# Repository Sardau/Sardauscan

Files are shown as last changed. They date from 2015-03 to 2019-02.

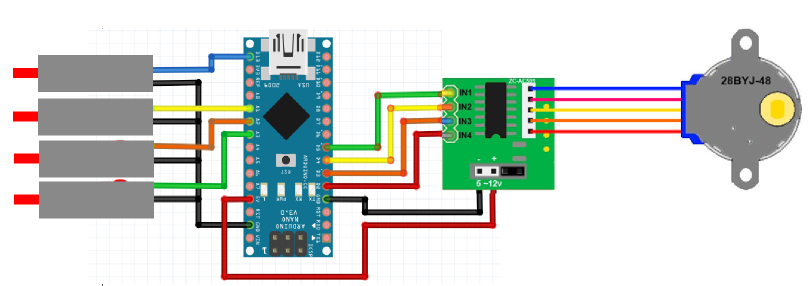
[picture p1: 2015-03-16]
FirmWare/Wiring.png

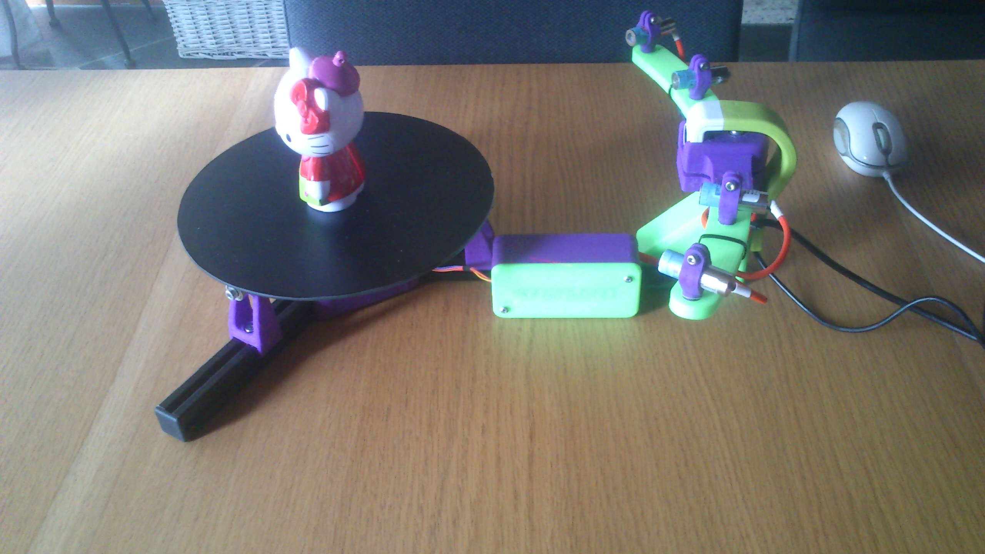
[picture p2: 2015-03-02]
STL/DSC_0299.jpg

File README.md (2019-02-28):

# Sardauscan

Sardauscan is a 3D laser scanner aimed to cost less than 30$

It is quite possibly the lowest-cost 3D scanner currently available.

Hardware List: 
- Arduino Nano
- 1 to 4 line lase
-a a micro geared stepper (28BYJ-48)
- Hercule HD Twist webcam

This software is written in C# and Winforms, and is based on a system of tasks and processes.

A task is an operation, such as: scan, save file, filter noise, smooth, or build mesh.

A process is simply a list of tasks.

It is possible to develop and add your own tasks via plugins.

The software will not be linked to any specific hardware.
Using plugins, one could add harware controllers for additional cameras, turn tables and lasers.
For example, if you wish to use another scanner or webcam.

Directory "Firmware" => code for the arduino
Directory "STL" the source stl and 123Design file.
Directory "Sardauscan" => the client software

The code is written in C# and Winforms and is build on Visual Basic 2010, for Windows.

the firmware needed for the Adafruit Motor Shield library can be found here:
https://github.com/adafruit/AccelStepper

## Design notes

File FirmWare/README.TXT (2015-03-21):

Hello you must install the accellstepper library in arduino environement before compile/upload it it

https://github.com/adafruit/AccelStepper

tips (from Mark Benson)
If anyone else is having problems with a BYJ48 stepper not doing anything, change the HALFSTEP value to 4 & REVOLUTION_STEP to 2048 in configuration.h.

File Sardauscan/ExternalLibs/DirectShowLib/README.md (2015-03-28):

Library **DirectShowLib** is not a part of Camera_Net library.

DirectShowLib is included in repo just to give an ability to build project/solution without any additional work.

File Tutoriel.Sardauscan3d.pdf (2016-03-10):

# Tutoriel d’utilisation du Sardauscan

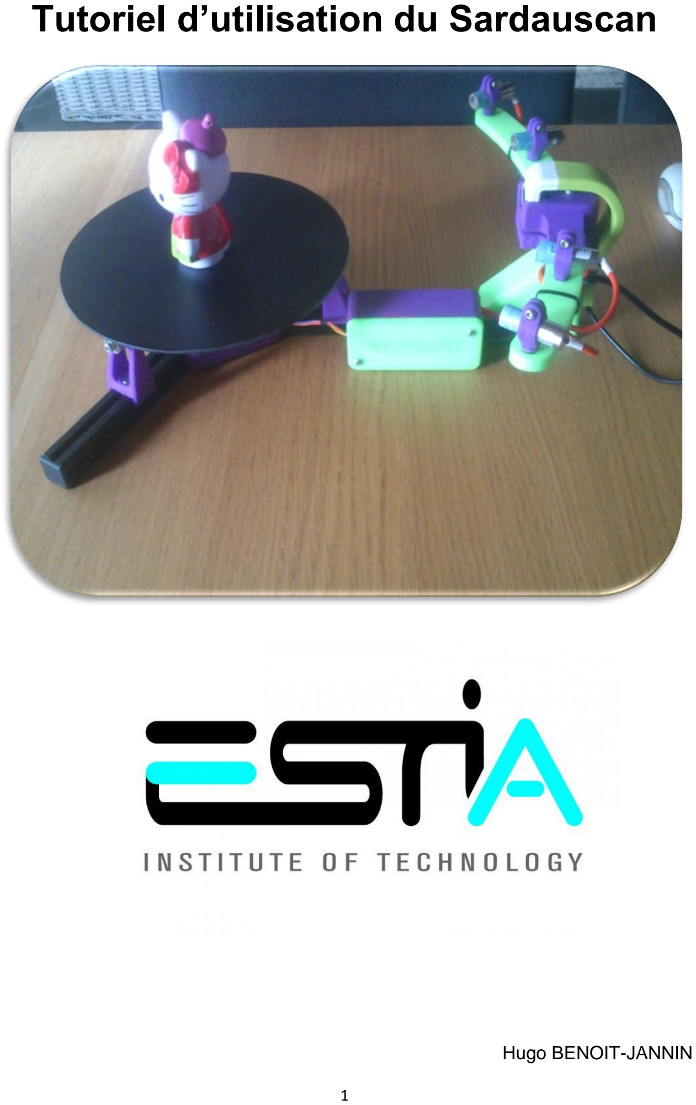
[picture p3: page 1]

Hugo BENOIT-JANNIN

Ce manuel d’utilisation traite uniquement des démarches pour calibrer et scanner un objet en 3D avec le scanner Sardauscan, la partie conception du scanner ne sera pas abordée dans ce tutoriel. Si vous souhaitez construire votre Sardauscan rendez-vous sur le site suivant : http://www.thingiverse.com/thing:702470 où tout est indiqué (matériel à acheter, programme pour l’Arduino, design des pièces à imprimés).

Le Sardauscan est un scanner 3D à bas coût et open-source, pouvant rivaliser avec de très bon scanner « plug and play » coûtant d’avantage et fermés à toute modification.

Le Sardauscan utilise des faisceaux lumineux de couleur rouge, qui seront détectés par la Webcam, la webcam enregistre la déformation du faisceau lumineux pour ensuite la traduire comme image sur le logiciel.

Prévoir un grand espace autour du scanner pour éviter que le scan enregistre les formes trop proches, ce qui provoque du bruit et fausse le scan.

# Sommaire

- Installation du logiciel d’interface __________________________3-8
- Calibration du matériel________________________________9-17
- Calibration caméra___________________________________10
- Calibration laser_____________________________________11
- Calibration position___________________________________12
- Calibration image laser________________________________13
- Calibration matrice __________________________________14-16
- Scan et traitement _____________________________________17-18
- Quelques scans _______________________________________19-23

## Installation du logiciel d’interface

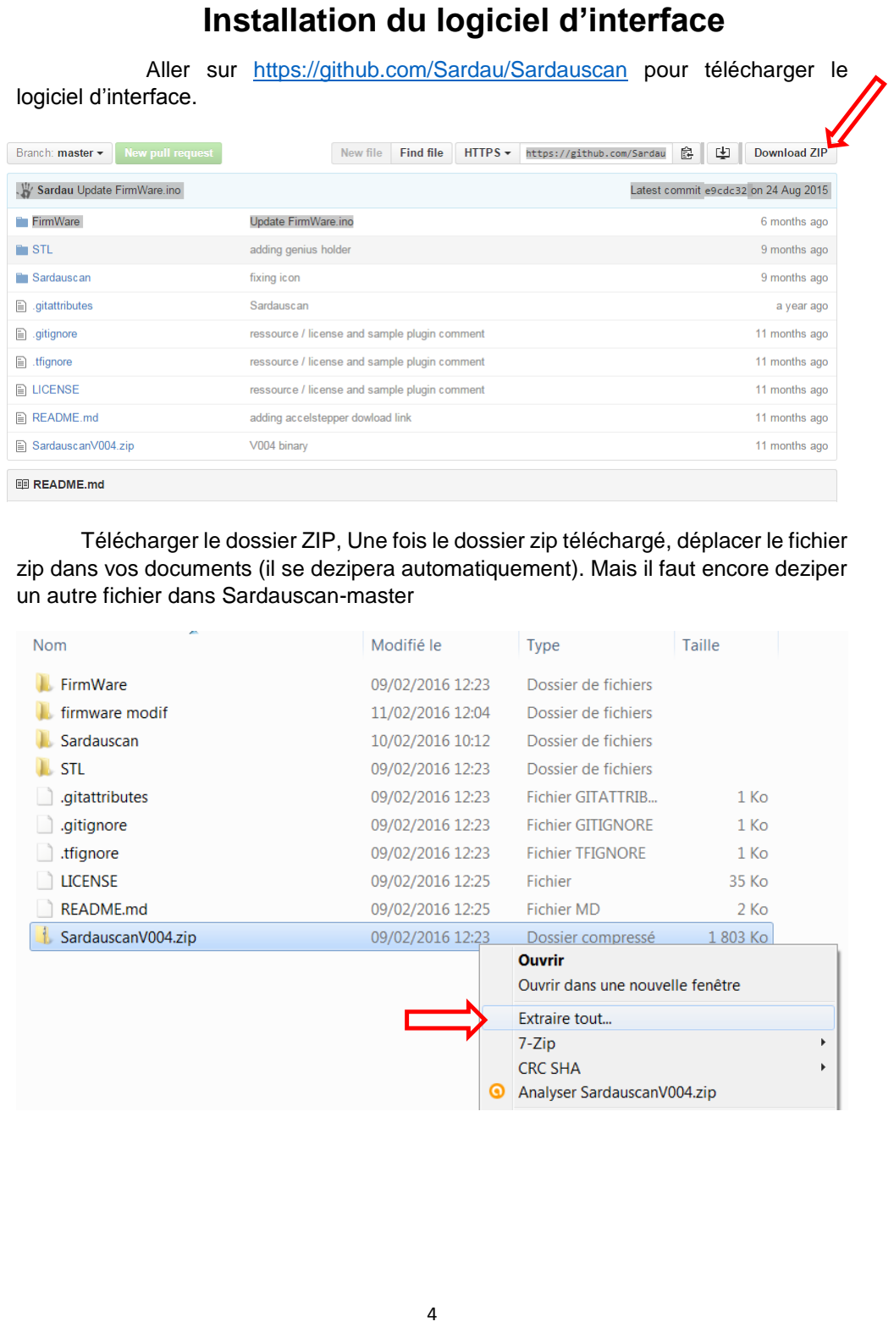
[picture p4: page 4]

Aller sur https://github.com/Sardau/Sardauscan pour télécharger le logiciel d’interface.

Télécharger le dossier ZIP, Une fois le dossier zip téléchargé, déplacer le fichier zip dans vos documents (il se dezipera automatiquement). Mais il faut encore deziper un autre fichier dans Sardauscan-master

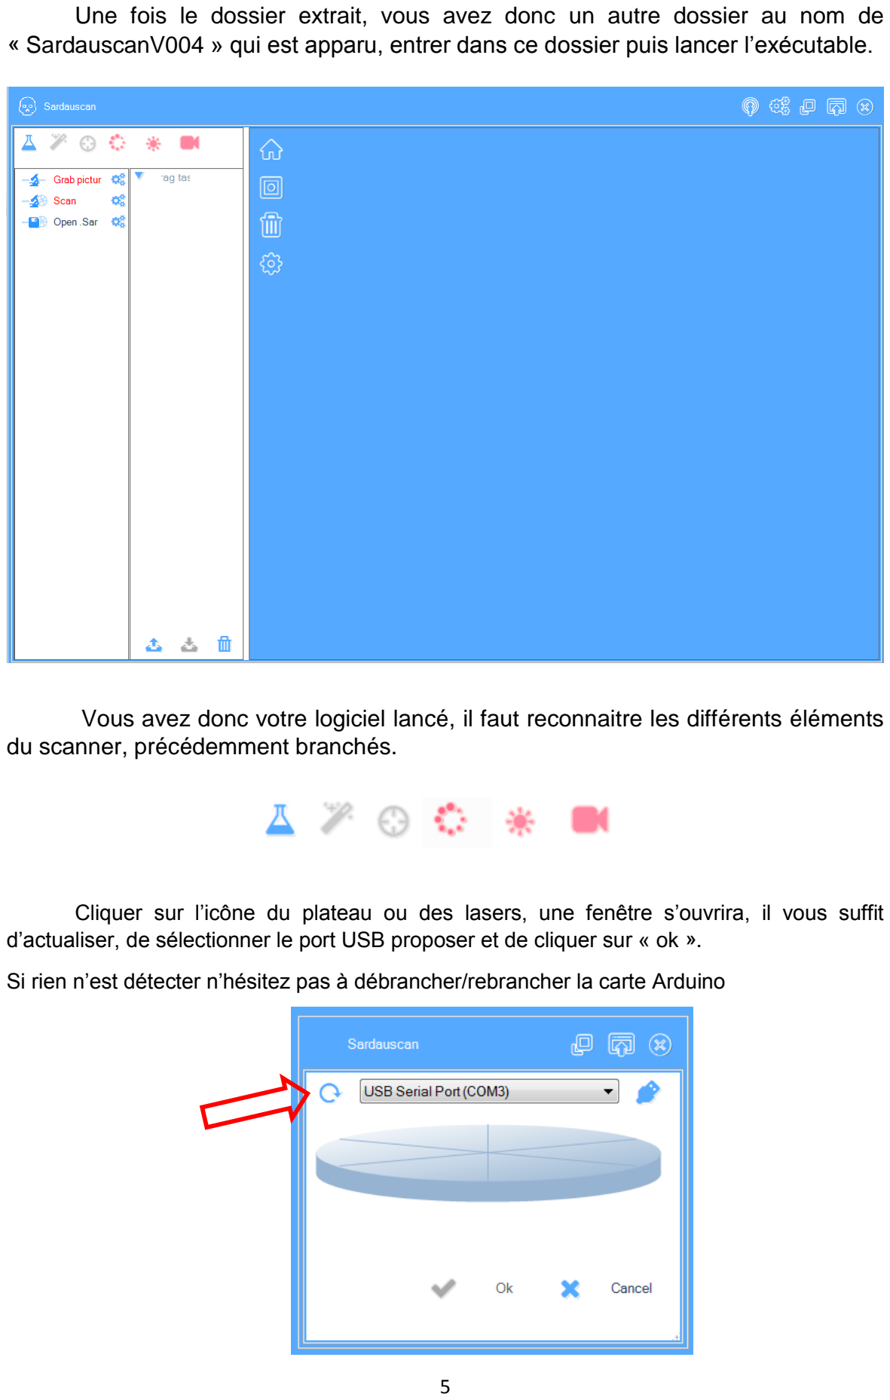
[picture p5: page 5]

Une fois le dossier extrait, vous avez donc un autre dossier au nom de « SardauscanV004 » qui est apparu, entrer dans ce dossier puis lancer l’exécutable.

Vous avez donc votre logiciel lancé, il faut reconnaitre les différents éléments du scanner, précédemment branchés.

Cliquer sur l’icône du plateau ou des lasers, une fenêtre s’ouvrira, il vous suffit d’actualiser, de sélectionner le port USB proposer et de cliquer sur « ok ».

Si rien n’est détecter n’hésitez pas à débrancher/rebrancher la carte Arduino

Pour la caméra vérifier même si l’icône est bleu en effet le logiciel peut avoir reconnu la camera intégrée si vous utilisez un ordinateur portable. Pour retirer la caméra intégrée faire clic droit sur l’icône puis « remove ».

Choisissez alors « Hercules HD Twist » puis cliquer sur « ok »

Vous pouvez normalement utiliser indépendamment chaque laser et le plateau en cliquant sur l’icône laser, puis en activant chaque laser indépendamment.

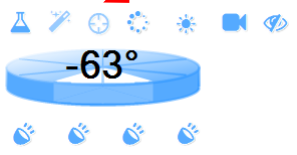
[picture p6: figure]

Il est probable que le plateau ne tourne pas, vérifier si des LEDs sur la carte électronique du moteur sont allumées, si elles sont allumées le plateau fonctionne, si ce n’est pas le cas, il faut modifier quelques paramètres dans le code Arduino.

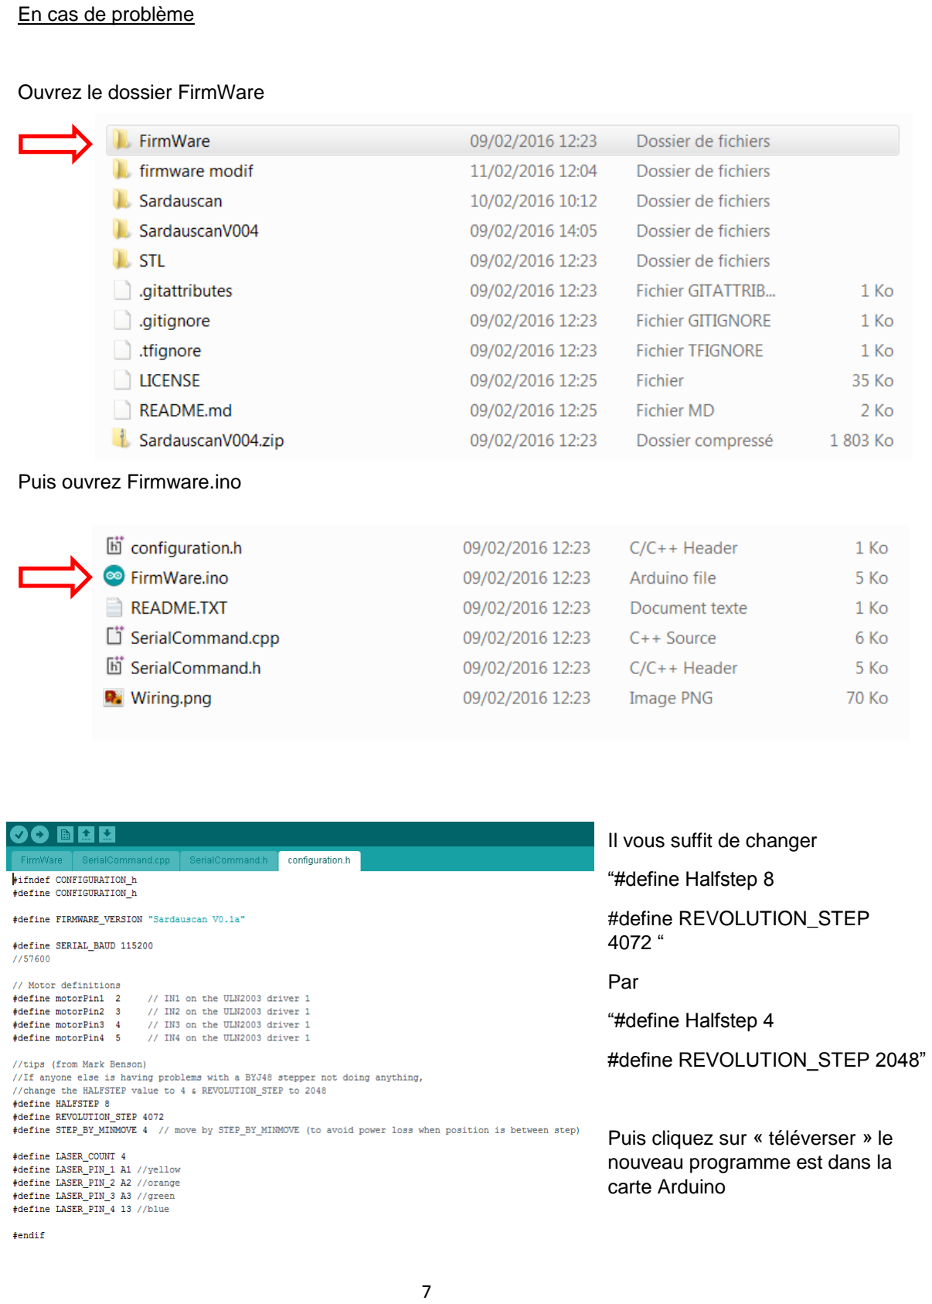
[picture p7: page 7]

En cas de problème

Ouvrez le dossier FirmWare

Puis ouvrez Firmware.ino

Il vous suffit de changer

“#define Halfstep 8

#define REVOLUTION_STEP

4072 “

Par

“#define Halfstep 4

#define REVOLUTION_STEP 2048”

Puis cliquez sur « téléverser » le nouveau programme est dans la carte Arduino

Un message d’erreur peut apparaitre, en effet il peut manquer une librairie dans votre
logiciel Arduino. Pour cela aller sur | https://github.com/adafruit/AccelStepper | et
télécharger le dossier, et renommer le « AccelStepper » en respectant les minuscules/majuscules.

Retourner dans le logiciel Arduino

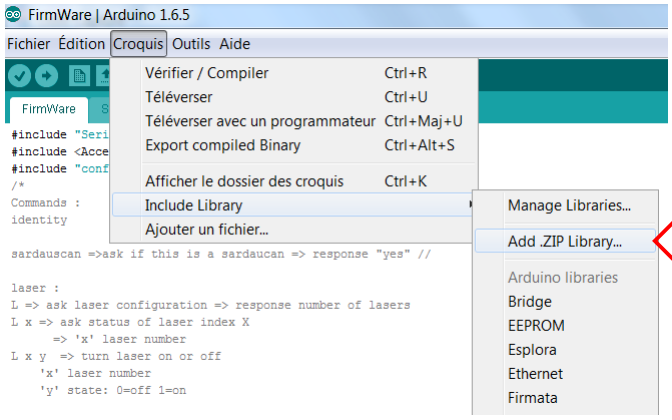
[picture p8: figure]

Ajouter la librairie AccelStepper, puis téléverser le nouveau programme, ce dernier devrait alors s’implanter dans votre Arduino sans soucis.

Votre interface est maintenant prête à l’utilisation, mais il faut maintenant calibrer le scanner.

## Calibration du matériel

Nous allons maintenant calibrer le scanner, cette tâche est la plus longue et la plus compliquée, mais il est nécessaire que le calibrage soit fait avec soin pour obtenir un résultat de bonne qualité, soyez donc patient et précis.

Pour calibrer je vous conseille d’imprimer en 3D un demi-cône (coupé dans la hauteur) et de faire une rainure dans sa hauteur (dans le sens des lasers), faites le de couleur noir, ce qui évite la diffusion de la lumière à travers la matière, ce qui peut fausser notre précision.

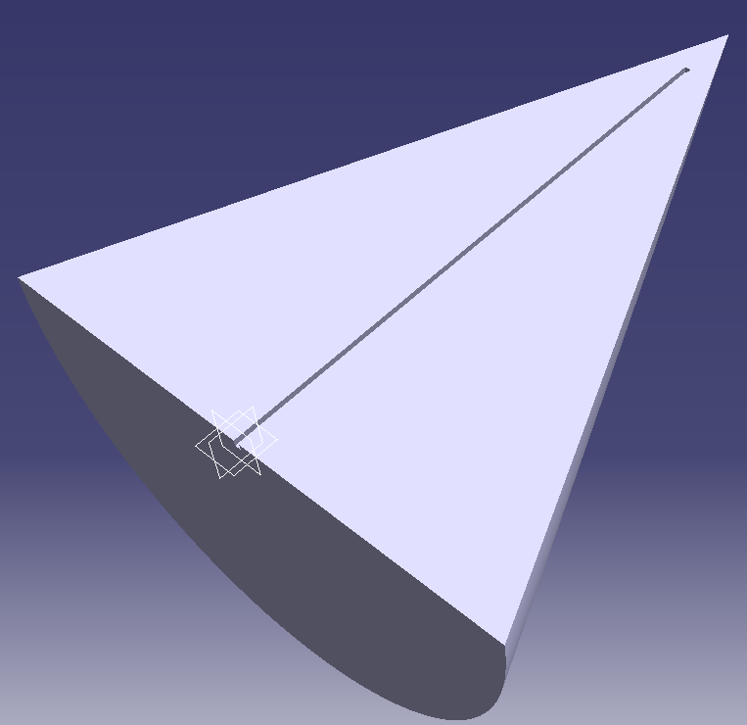
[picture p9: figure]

Vous avez préalablement trouvé le centre de votre plateau tournant si ce n’est pas le cas il faut essayer de le déterminer, vous pouvez vous aidez à l’aide de votre demi-cône et de vos lasers. Posez votre demi-cône sur le plateau et faites passer un laser par son sommet, puis faites tourner le plateau, si le laser reste toujours en son sommet, vous avez trouvé le centre du plateau (marquez son centre pour les prochaines utilisations du scanner).

## Calibration camera

Pour calibrer la camera rien de plus simple, aller dans l’onglet caméra, puis dans la section « Physical calibration »

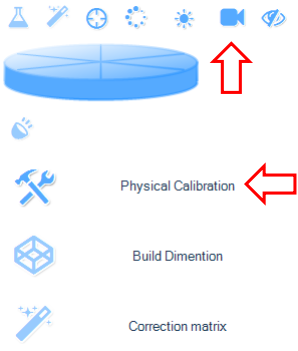
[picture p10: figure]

Il vous suffit de cliquer la barre verte horizontale et de la placer au centre de votre plateau, ainsi votre camera sera calibrée pour les scans ultérieurs.

## Calibration lasers

La calibration des lasers est une des tâches les plus compliquées à effectuer par sa précision. Vous devrez effectuer l’opération pour chaque laser indépendamment. Vous avez besoin de votre demi-cône que vous placerez au centre du plateau, la face plate du côté de la caméra.

Réglez le faisceau lumineux afin d’avoir le plus fin possible en tournant la molette directement sur le laser. Puis diriger le faisceau lumineux dans la rainure du demi-cône (la rainure est au centre du plateau). Sur votre image que vous avez à l’écran vous ne devez pas distinguer le laser derrière la barre verte (voir ci-dessous).

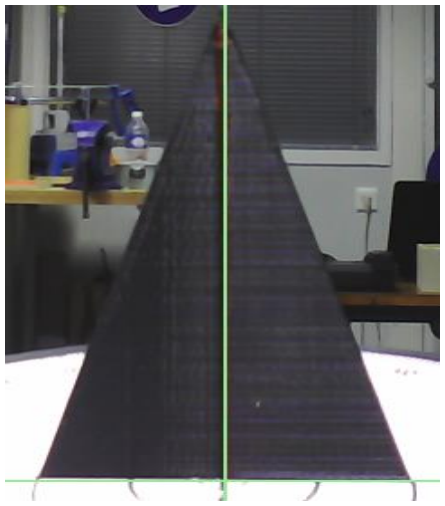
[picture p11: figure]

## Calibration Position

Si ce n’est pas déjà fait, il faut calibrer les dimensions de votre scanner, c’est-à-dire des positions de votre caméra et de vos différents lasers, pour cela allez dans l’onglet « calibrate », puis dans « build calibrate » et rentrez les coordonnées de la caméra.

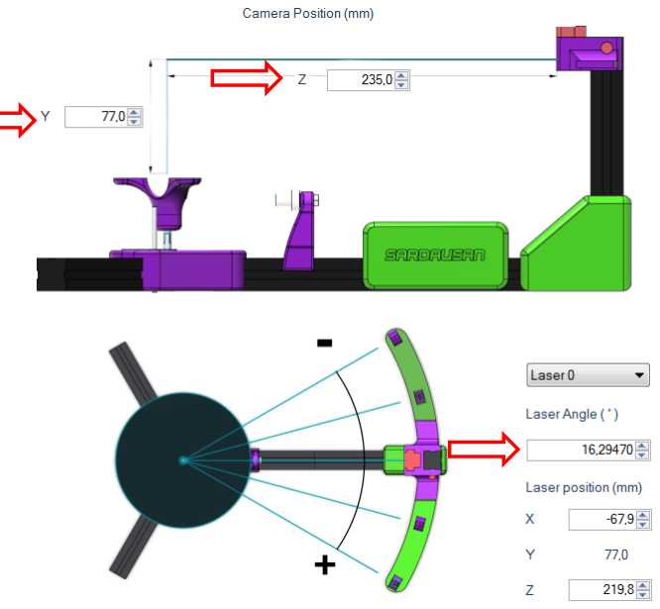
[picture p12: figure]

Conseil : Ne mettez que l’angle du laser en respectant le signe, ses coordonnées s’ajusteront toutes seules. Vérifiez bien tous les angles de laser qui peuvent bouger en réglant les autres lasers.

Conseil : imprimer un rapporteur circulaire que vous collerez sur le plateau

## Calibration de l’image laser

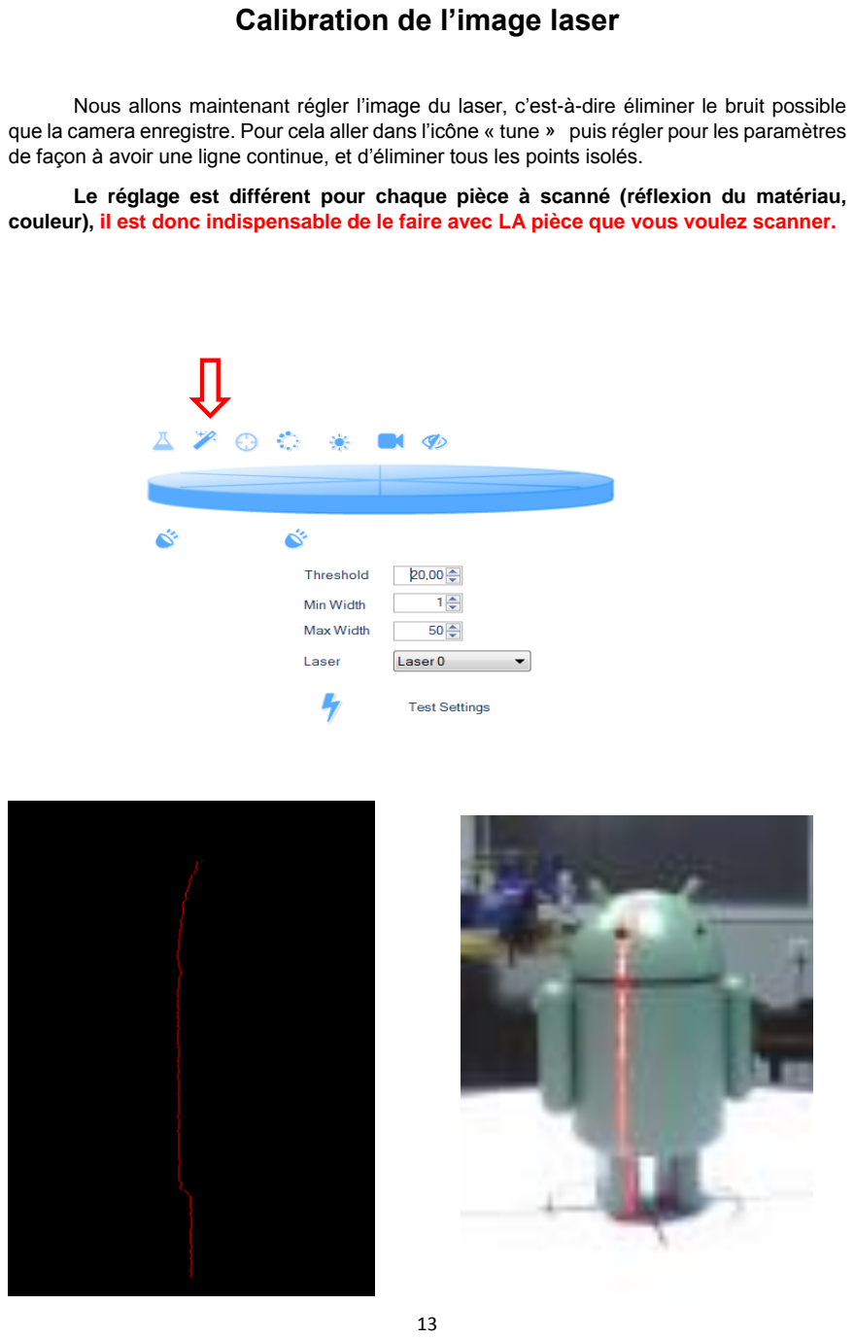
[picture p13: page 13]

Nous allons maintenant régler l’image du laser, c’est-à-dire éliminer le bruit possible que la camera enregistre. Pour cela aller dans l’icône « tune » puis régler pour les paramètres de façon à avoir une ligne continue, et d’éliminer tous les points isolés.

Le réglage est différent pour chaque pièce à scanné (réflexion du matériau, couleur), il est donc indispensable de le faire avec LA pièce que vous voulez scanner.

## Correction de matrice

La correction de matrice est la dernière étape de calibration du scanner et la plus importante. Pour cela prenez une pièce ayant une forme particulière, un tube avec une barre le traversant dans son rayon voir photo suivante

Votre objet de calibration doit avoir une forme simple tout en étant irrégulier (ex : pas de tube simple).

Maintenant aller dans l’onglet « calibrate » puis dans « correction matrix »

Chaque réglage est propre à votre environnement, à vous de le trouver pour obtenir une ligne continue sans point isolé.

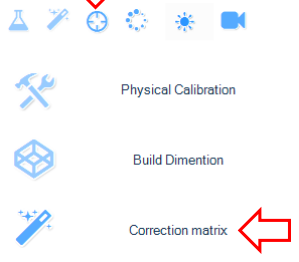
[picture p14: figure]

Poser votre objet de calibrage au centre du plateau, puis lancer un scan rapide. Vous obtiendrez alors des formes dans votre fenêtre (vue de dessus) il vous suffit donc d’aligner vos scans de différentes couleurs pour en faire un seul.

Conseil : Aller voir dans l’onglet « Process » et regarder quelle couleur de scan respecte l’échelle de l’objet scanné, ne pas toucher au scan respectant l’échelle et aligner les autres. Si les scans ne sont pas à l’échelle mais qu’ils sont alignés, une fonction du traitement permet de corriger cette erreur.

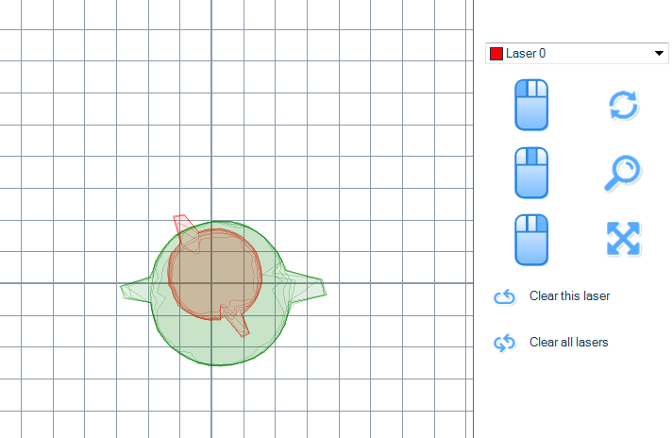
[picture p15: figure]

Ici le vert respecte les dimensions, il faut donc aligner le scanner rouge sur le vert, avant toute manipulation cliquer sur « clear this scan » et faites-le pour chaque scan.

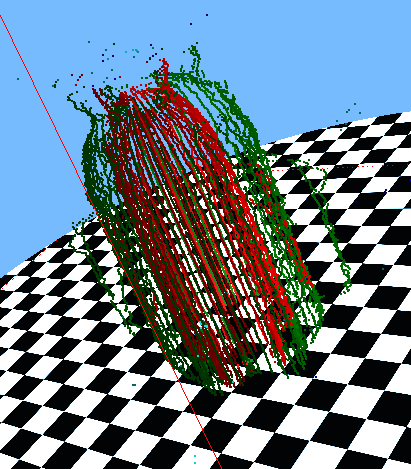
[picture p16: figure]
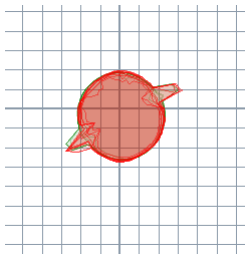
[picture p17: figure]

On remarque dans « process » que le scan rouge est plus « maigre » que le scan vert, et que le scan vert est à bonne échelle, il faut donc s’aligner sur le scan vert.

Votre scan est désormais calibré, nous allons pouvoir procéder aux scans puis au traitement pour éliminer le bruit et lisser les scans.

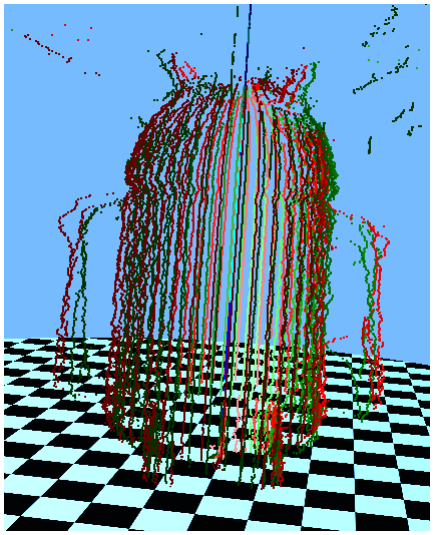
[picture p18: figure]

## Scan et traitement

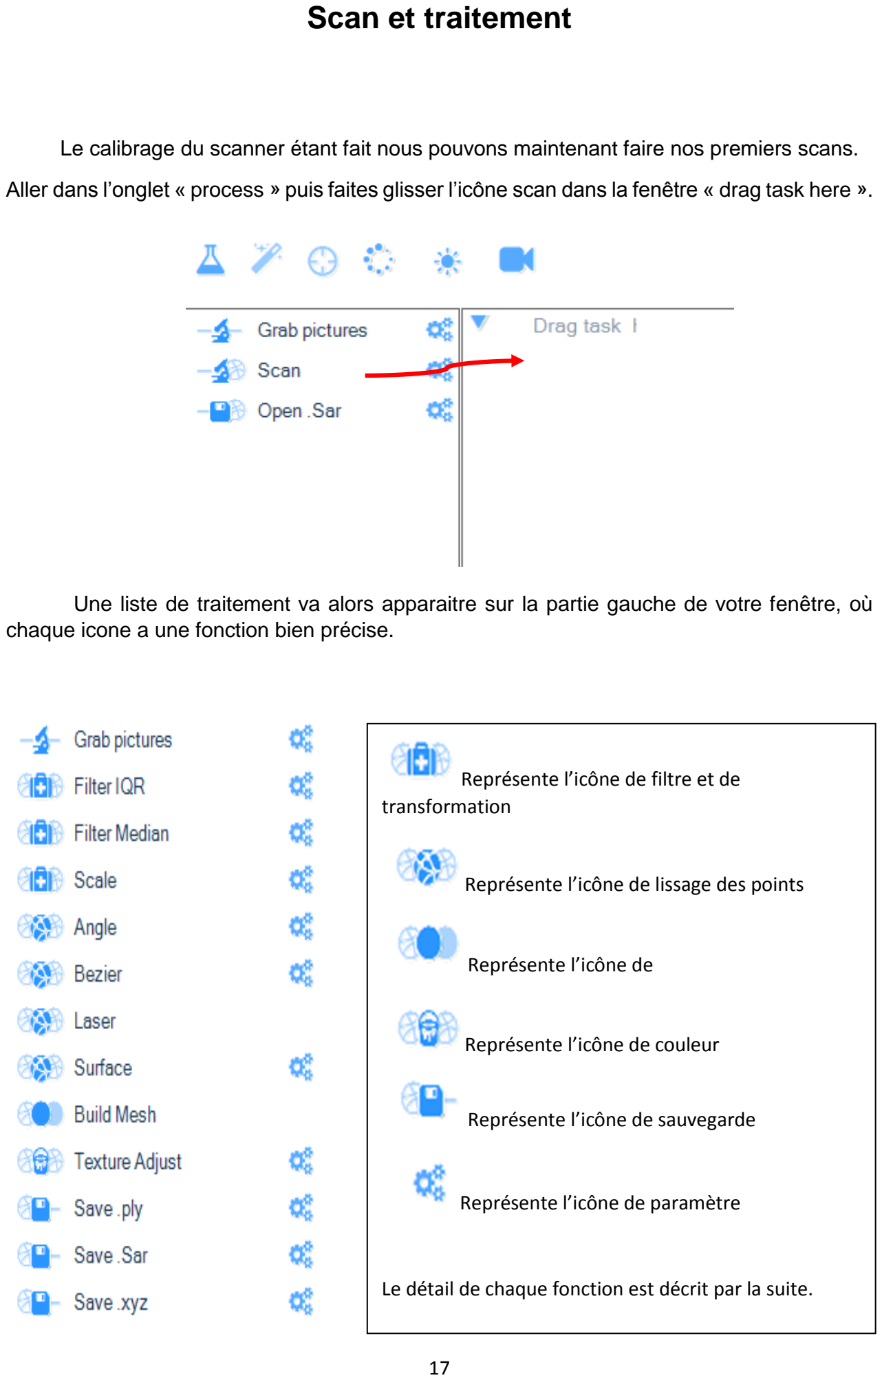
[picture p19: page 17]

Le calibrage du scanner étant fait nous pouvons maintenant faire nos premiers scans.

Aller dans l’onglet « process » puis faites glisser l’icône scan dans la fenêtre « drag task here ».

Une liste de traitement va alors apparaitre sur la partie gauche de votre fenêtre, où chaque icone a une fonction bien précise.

Représente l’icône de filtre et de transformation

Représente l’icône de lissage des points

Représente l’icône de

Représente l’icône de couleur

Représente l’icône de sauvegarde

Représente l’icône de paramètre

Le détail de chaque fonction est décrit par la suite.

Filter:

Filter IQR : Retire les erreurs de scan avec un filtre IQR (filtre standard dans les échantillons de probabilités).

Filter Median : Retire les erreurs de scan avec un filtre « Median filter » (filtre standard dans l’imagerie).

Transformation :

Scale : Change l’echelle en (x,y,z).

Lissage:
angle : Fait une approximation moyenne de toutes les scanlines en fonction d’un angle.

Laser : Fait une approximation moyenne de toutes les scanlines en fonction d’un angle.

Bézier : Fait une approximation de Bézier sur chacune des scanlines.

Surface : Fait un lissage de surface avec une Laplace simplifiée.

Couleur:

Texture Adjust : ajuste la luminosité, le contraste et le gamma de la texture.

Sauvegarde :
Load Sar : ouvre un fichier « .sar ».

Save xxx : Sauve un fichier xxx. (xxx, est pour ply,xyz, ect).

Les fichiers .ply et .xyz sont là si vous préférez utiliser un programme de reconstruction de surface plus performant comme « Meshlab » ou autre.

Les fichiers .stl et .obj sont là pour les slicer (Les fichier .obj peuvent être importés dans les modeleur 3D comme « 3ds Max » ou « Blender ».

Conseil : Il est conseillé de faire le scan brut puis de l’enregistrer pour ensuite uniquement travailler sur le traitement de nuage de points. Vous devez donc à glisser l’icône scan puis l’icône « IO:save.sar » dans la fenêtre de droite.

Puis d’importer votre fichier .sar dans le logiciel pour appliquer le traitement

## Quelques scans

Voici quelques exemples de scans avec différents objets et des traitements différents, je n’utilise que deux lasers pour le moment, qui sont placés en position 1 et 2, soient les positions les plus proches de la caméra.

Les scans sont très sensibles à l’environnement extérieur et donc aux paramètres que l’on doit appliquer pour avoir un rendu correct. Je vous conseille donc d’être dans une pièce pas trop lumineuse et de ne pas mettre le scan en lumière direct et sous une lampe, en effet trop de luminosité diminue la précision du laser et la lumière extérieure peut varier et donc modifier la qualité du scan.

Les objets qui tiennent sur des « jambes » ou « pattes » ne sont pas idéaux a scanner puisque le sol sera alors scanné et peut être mal interprétés lors du traitement des objets.

Les objets brillants sont également déconseiller car la matière diffuse le laser et la caméra ne capte pas la déformation.

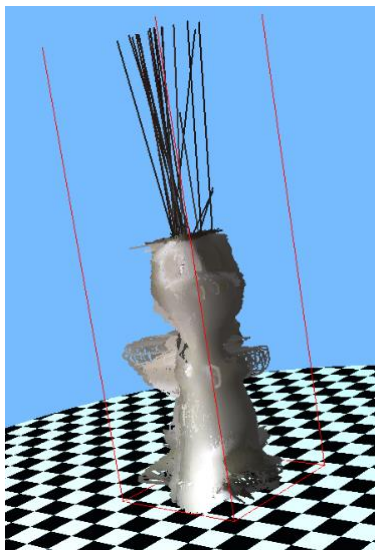
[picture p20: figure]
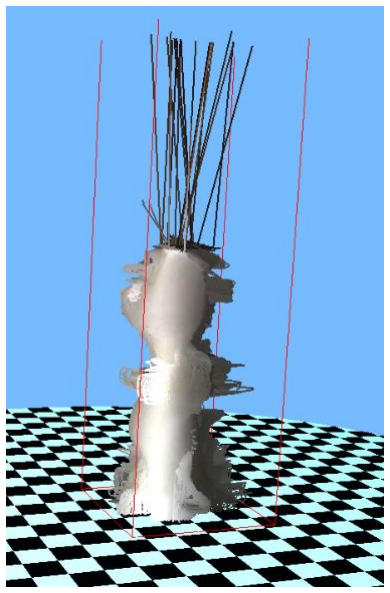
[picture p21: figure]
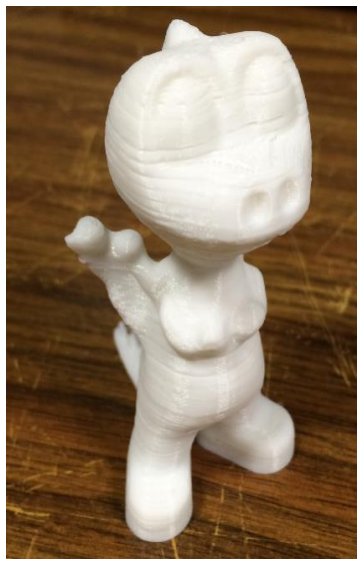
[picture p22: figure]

Ici on remarque que le dragonnet qui est lui-même imprimé en matériau d’imprimante 3D manque de détails au niveau du dos, des mains et la queue est manquante. On remarque des piques au-dessus de son crâne du fait que le scan n’a pas pris les points du crâne (non visible) et a relié directement avec des points parasites.

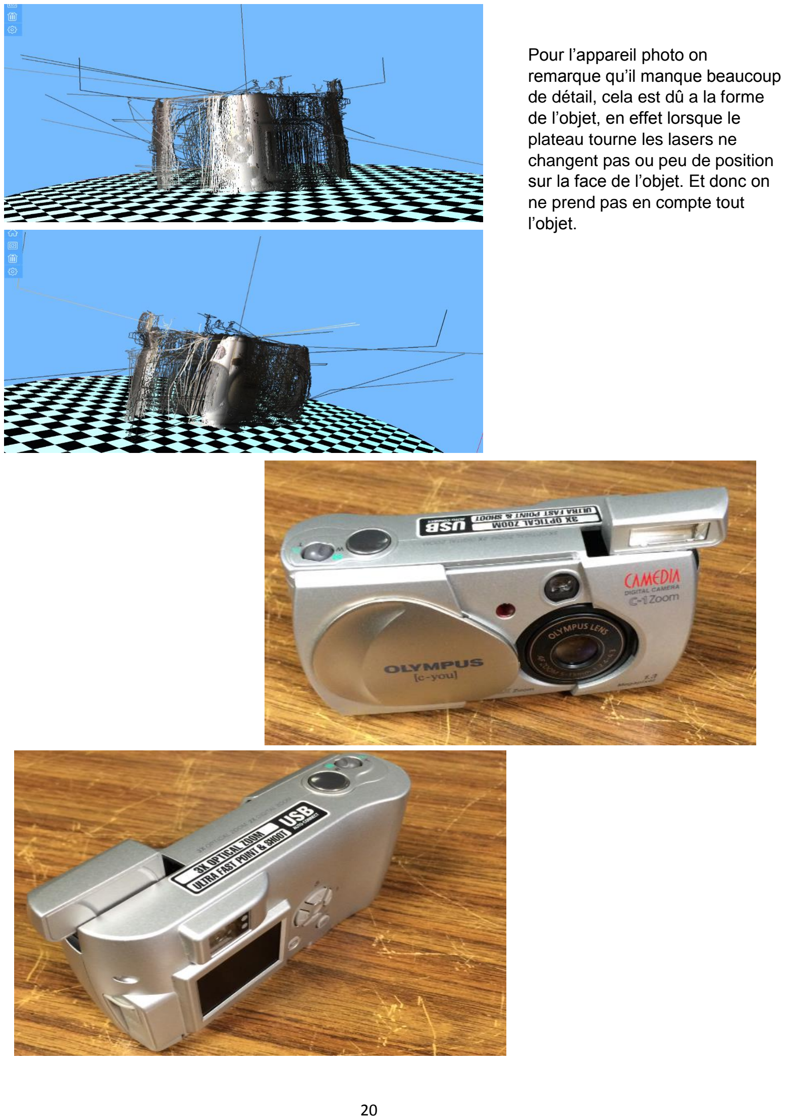
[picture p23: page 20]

Pour l’appareil photo on
remarque qu’il manque beaucoup de détail, cela est dû a la forme de l’objet, en effet lorsque le plateau tourne les lasers ne changent pas ou peu de position sur la face de l’objet. Et donc on ne prend pas en compte tout l’objet.

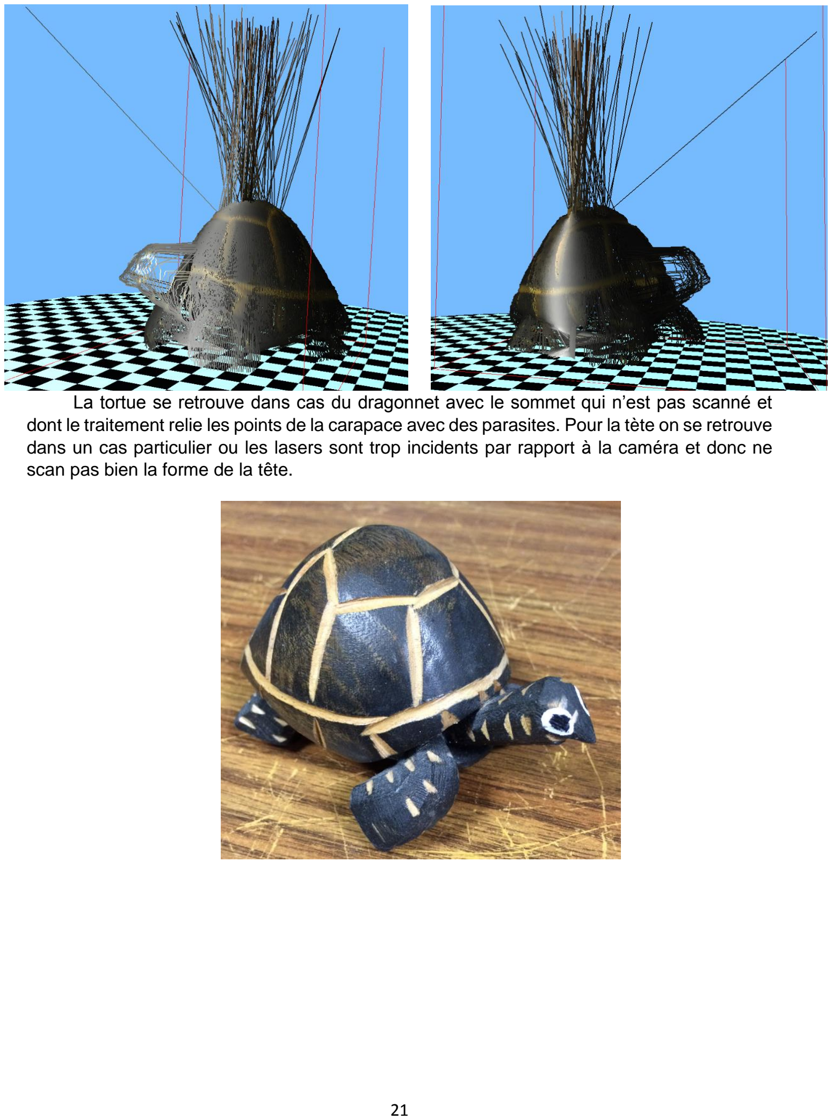
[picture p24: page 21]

La tortue se retrouve dans cas du dragonnet avec le sommet qui n’est pas scanné et dont le traitement relie les points de la carapace avec des parasites. Pour la tète on se retrouve dans un cas particulier ou les lasers sont trop incidents par rapport à la caméra et donc ne scan pas bien la forme de la tête.

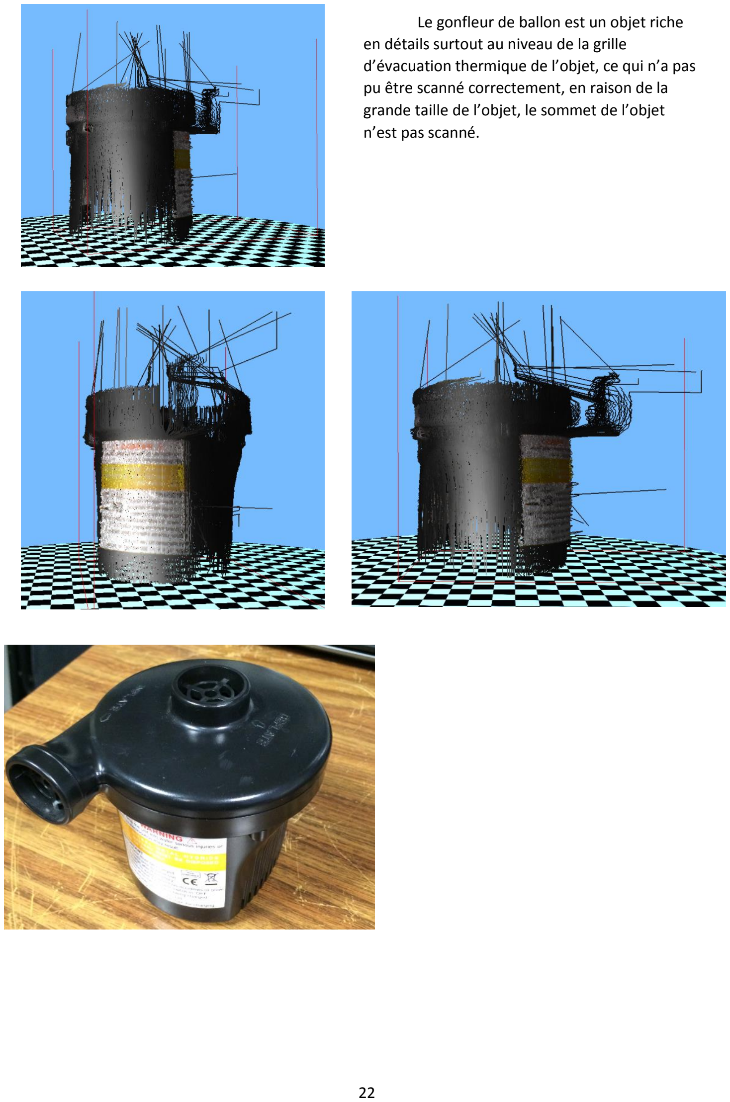
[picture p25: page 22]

Le gonfleur de ballon est un objet riche en détails surtout au niveau de la grille d’évacuation thermique de l’objet, ce qui n’a pas pu être scanné correctement, en raison de la grande taille de l’objet, le sommet de l’objet n’est pas scanné.

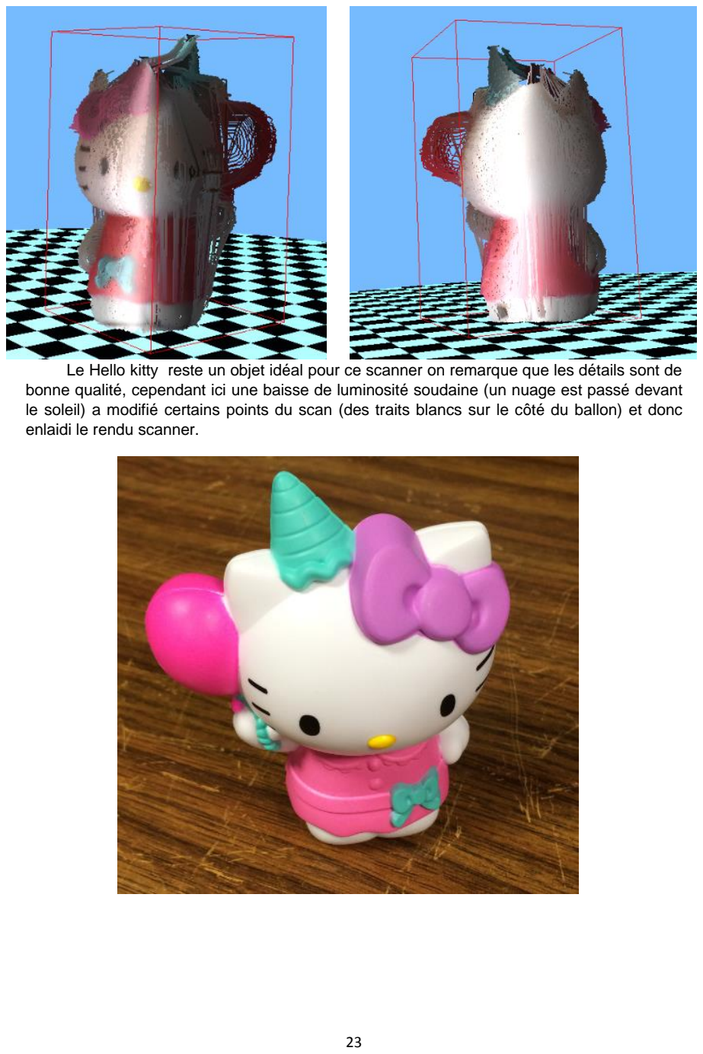
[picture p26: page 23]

Le Hello kitty reste un objet idéal pour ce scanner on remarque que les détails sont de bonne qualité, cependant ici une baisse de luminosité soudaine (un nuage est passé devant le soleil) a modifié certains points du scan (des traits blancs sur le côté du ballon) et donc enlaidi le rendu scanner.

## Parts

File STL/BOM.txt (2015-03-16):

Bunch of M3 (16 and 20 mm)

Bunch of M4 (12 ans 20 mm)

1x chinese Arduino nano (chinese copy, 4$) http://www.befr.ebay.be/itm/NEW-Nano-V3-0-ATmega328-Controller-Board-5V-16M-CH340G-USB-Driver-For-Arduino-/141433274102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

1x chinese Stepper Motor and controler (5$) http://www.befr.ebay.be/itm/Uln2003-Stepper-Motor-Drive-Driver-Stepper-Motor-Controllers-5V-4-Phase-5-Line-/261743645463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

1-4x Line laser (2.5$ piece) http://www.befr.ebay.be/itm/251688838898?ssPageName=STRK:MEWNX:IT&_trksid=p3984.m1439.l2649

1x Hercule HD twist (15$) http://www.befr.ebay.be/itm/Hercules-HD-Twist-5-0-MP-720p-High-Definition-Mini-Web-Cam-Green-Edition-/381162889539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
20x20 profile ( can be printed : for exemple http://www.thingiverse.com/thing:280318)

optionnal 3x 4mm roller (0.3$ piece)

total 26.5$ (1 laser) to 35$ (4 lasers)

2020 lengths of my build (but you can use whatever you want, just make sure the camera can see all the scan area)
2x 140mm
1x 120mm
1x 250mm

you must install the accellstepper library in arduino to compile the firmware
https://github.com/adafruit/AccelStepper

what to print.
1 x arm_left.stl
1x box.stl
1x box_door.stl
1x box_arduino_clamp.stl
1x arm_right.stl
1x CORNER.stl
1X Camera_HOLDER_LOWER_PART.stl
1x MOTOR_MOUNT.stl
1 to 4 x laser_holder.stl
1x Camera_HOLDER_UPPER_PART.stl
1x center_axe_MINIMAL.stl OR 1x table_AXLE.stl
OPTIONAL
3x roller_baseV2.stl 
1x calibration.stl

you can print 12x M4_tslot_nut.stl if you use 20x20 profile and you don't have any

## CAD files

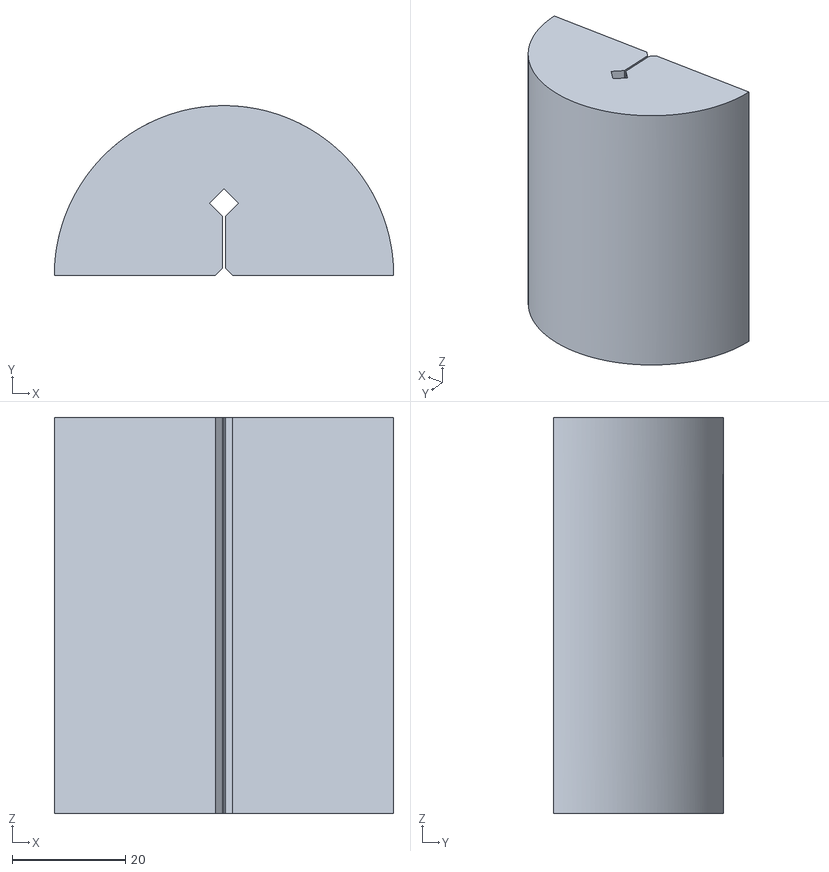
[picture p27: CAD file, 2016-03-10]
STL/calibrationV2.stl
60.0 x 30.0 x 70.0

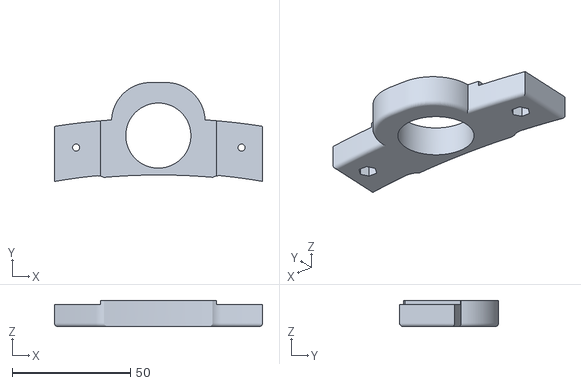
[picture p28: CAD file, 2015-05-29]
STL/Camera_HOLDER_Lower_genius_PART.stl
88.0 x 41.8 x 11.2

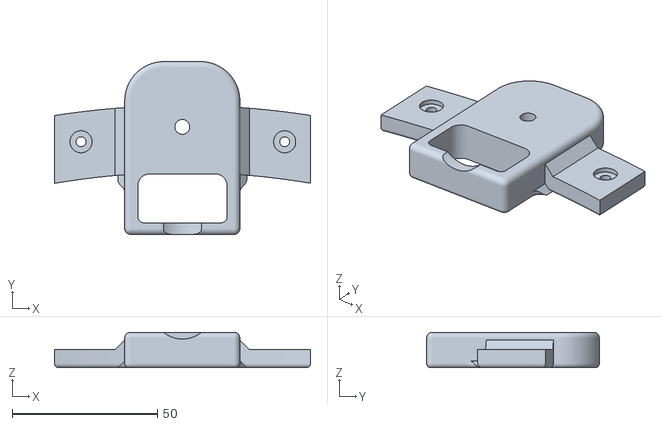
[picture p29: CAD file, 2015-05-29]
STL/Camera_HOLDER_Upper_genius_PART.stl
88.0 x 59.4 x 12.2

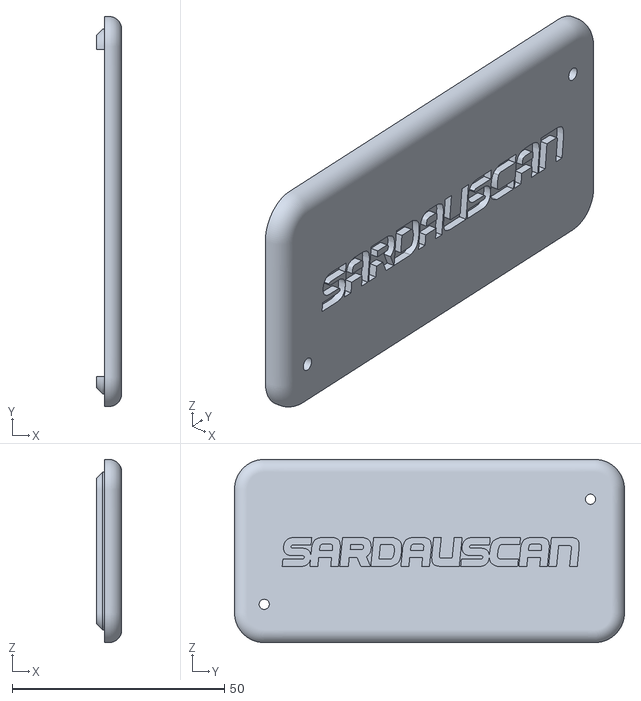
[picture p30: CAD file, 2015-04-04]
STL/box_door.stl
6.00 x 91.8 x 43.1

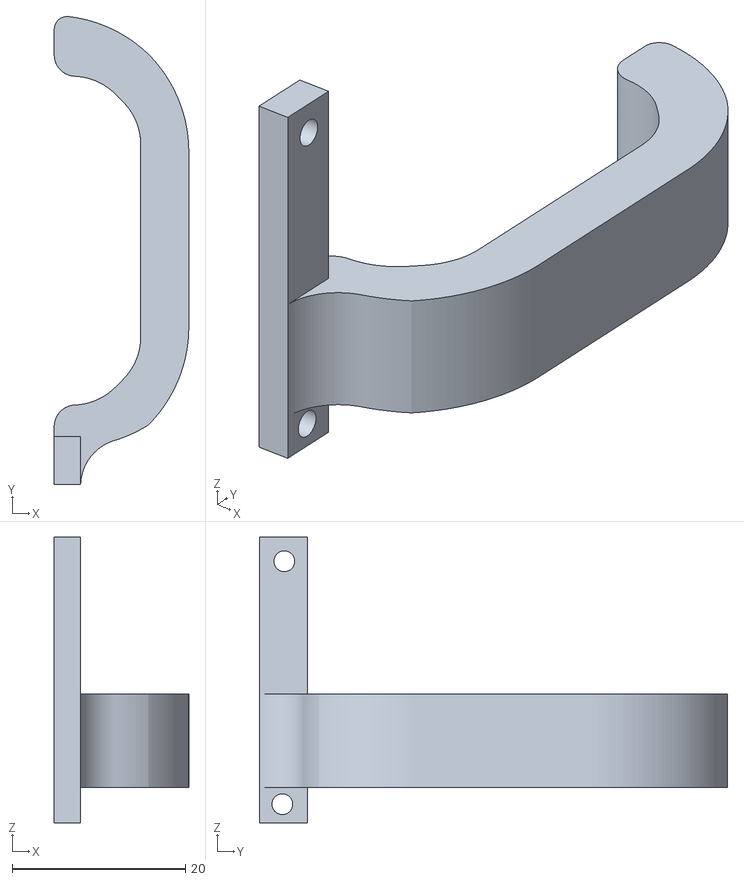
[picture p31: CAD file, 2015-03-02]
STL/box_arduino_clamp.stl
15.6 x 54.1 x 33.0

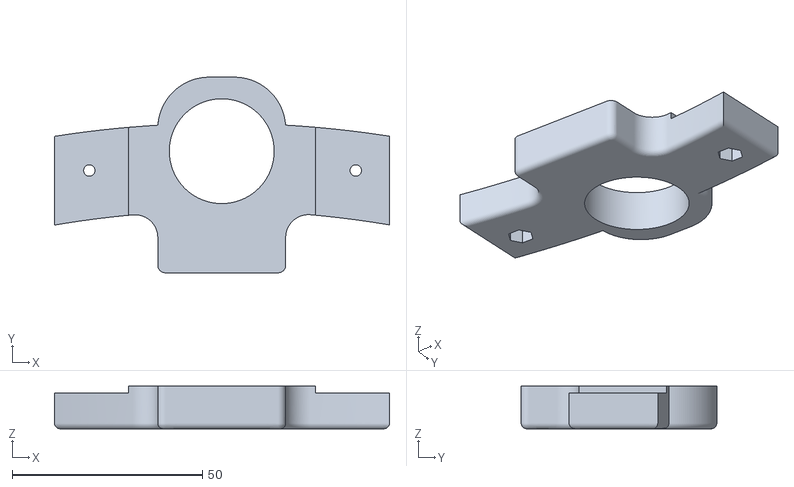
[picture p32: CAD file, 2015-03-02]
STL/Camera_HOLDER_LOWER_PART.stl
88.0 x 51.4 x 11.2

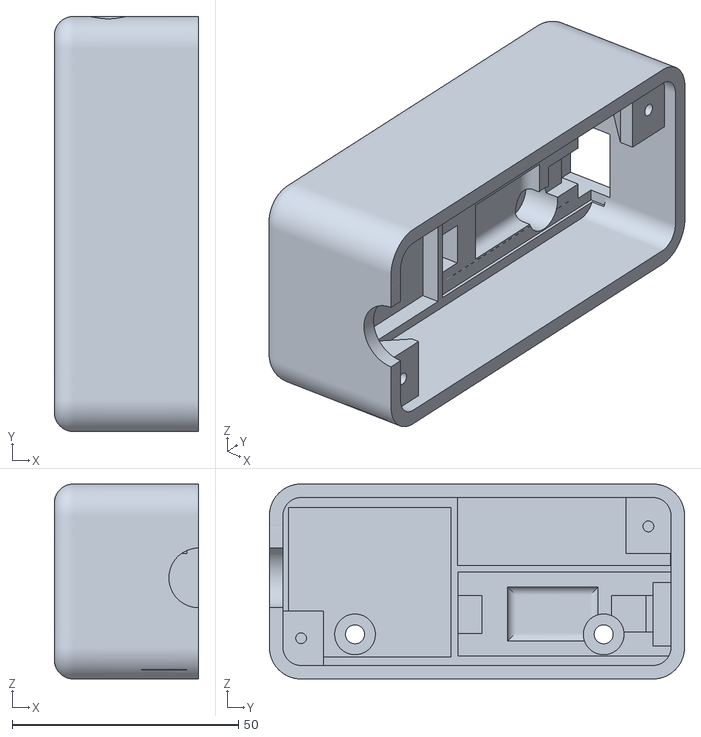
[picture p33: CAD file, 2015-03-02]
STL/box.stl
31.9 x 91.8 x 43.1

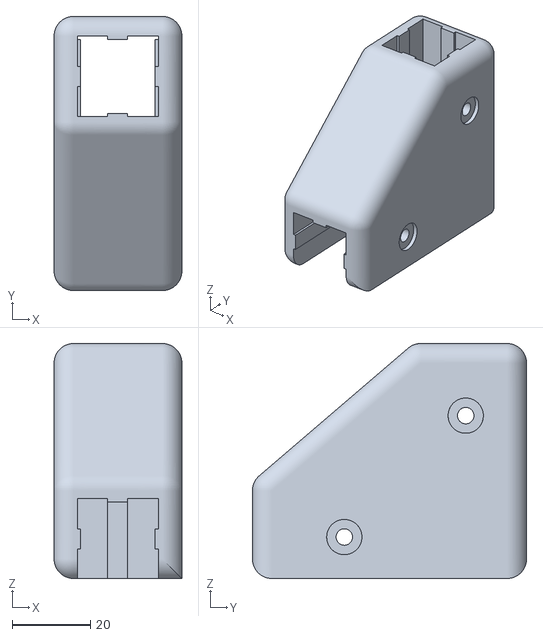
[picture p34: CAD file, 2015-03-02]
STL/CORNER.stl
32.7 x 70.0 x 60.0

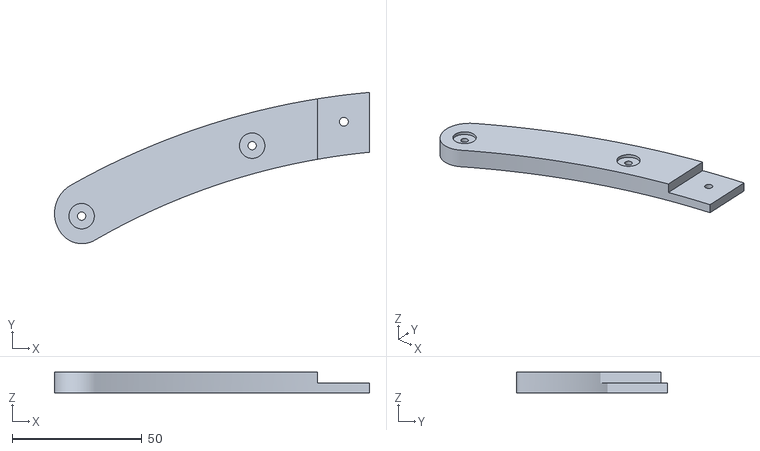
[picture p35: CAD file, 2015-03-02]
STL/arm_left.stl
121.5 x 58.3 x 8.00

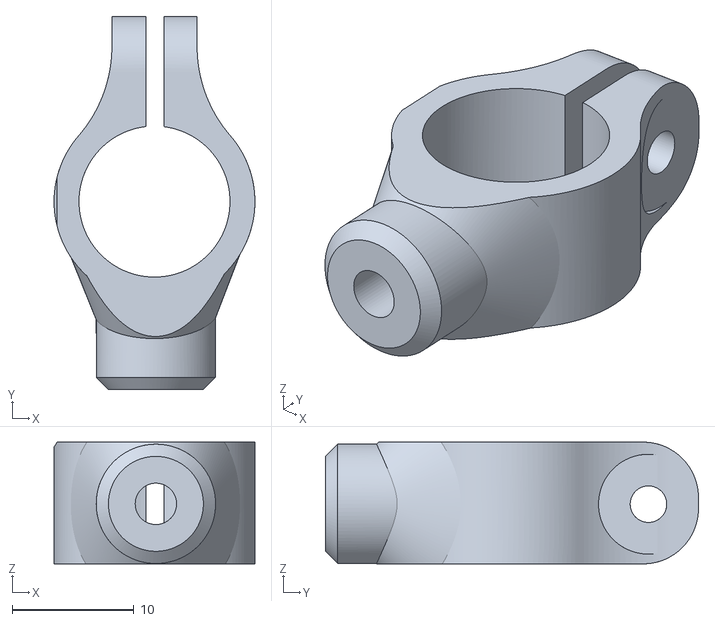
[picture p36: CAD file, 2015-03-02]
STL/laser_holder.stl
16.5 x 30.6 x 10.0

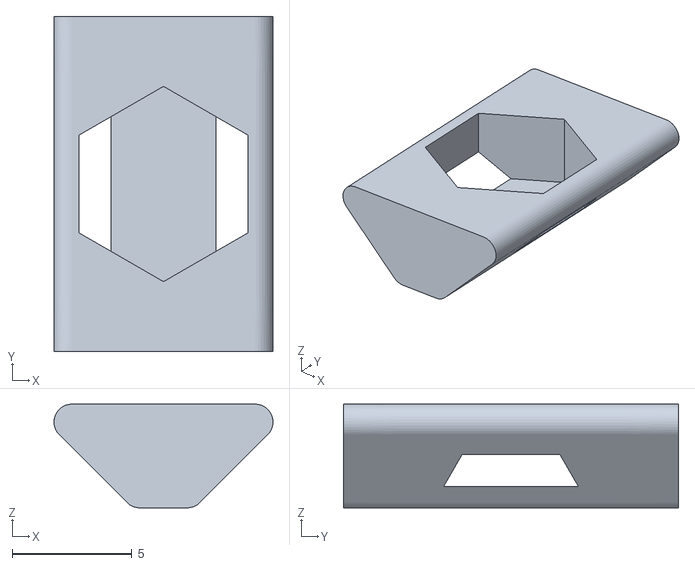
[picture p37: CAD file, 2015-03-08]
STL/M4_tslot_nut.stl
9.15 x 14.0 x 4.34

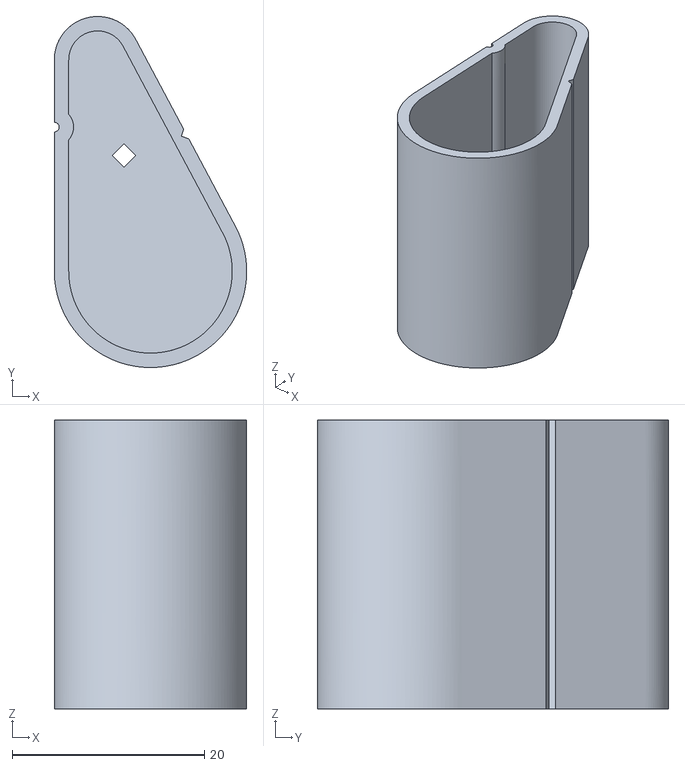
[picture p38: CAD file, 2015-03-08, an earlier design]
STL/calibration.stl
20.0 x 36.5 x 30.0

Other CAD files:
STL/arm_right.stl

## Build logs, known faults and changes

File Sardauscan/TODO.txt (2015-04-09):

Make 2 different file for PointCloud/ mesh

//COMMENT!! espacialy FAKE plugins

AutoCalibration
https://github.com/francisengelmann/FabScan/blob/master/sources/FabScanMac/FabScan3D/FSChessboardCalibration.cpp

-->
http://www.emgu.com/wiki/index.php/Main_Page

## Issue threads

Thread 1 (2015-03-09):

build documentation missing

MarcusWolschon, 2015-03-09:
the readme.md does not cover what operating software and build environment is required nor how to configure the software for a specific laser line scanner (e.g.Fabscan Cube)

Sardau, 2015-03-09:
Hello, the software does not work directly for a fabscan, it work out of the bow with his own firmware for the sardauscan hardware.

but a "IHardwareProxy" will surely be easy to implement (see https://github.com/Sardau/Sardauscan/tree/master/Sardauscan/FakeHardwarePlugins for sample plugins). I Didn't own a fabscan so i can't help you on that.

as soon as a IHardwareproxy plugin is available, nothing to do to configure the soft for a specific hardware.

Closed 2015-03-15.

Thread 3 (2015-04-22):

Allow user to choose from available cameras

frankvdh, 2015-04-22:
Working on a laptop with integrated webcam, I can't tell Sardauscan to use the camera plugged into the USB socket.

strawdog74, 2015-08-03:
It remembers the first selection you make, I had this problem too!

To start over, go into the main setting page (the cogs the on the top right of the window), and scroll down until you find the LAST USED section. Then erase the field ICamera_Proxy_HARDWARE_ID.

Close the program and restart and you should find the webcam is selectable.

Closed 2015-08-24.

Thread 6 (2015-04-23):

Typo in TableCommand processing

neildarlow, 2015-04-23:
In the TableCommand function (within FirmWare.ino) the last character test checks for 'C' or 's' which I believe came about as a cut and paste error.

This could have been avoided with a construct like:

switch( toupper(arg[0]) )
{
    case 'R': // T R
        ...
        break;

    case 'A': // T A
        ...
        break;

    case 'S': // T S
        ...
        break;

    case 'C': // T C
        ...
        break;

    default:
        Serial.print("Unknown Table command :");
        Serial.println(arg);
}

This would generate less code in that only a single uppercase check is performed per character and the compiler has good semantics for processing switch statements efficiently.

Sardau, 2015-08-24:
corrected thank you

Closed 2015-08-24.

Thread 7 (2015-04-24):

Wiring diagram mismatch with software

frankvdh, 2015-04-24:
The wiring diagram doesn't match up with the software as far as the lasers go:

Correct software to match the wiring diagram is:

#define LASER_PIN_1 13 //yellow
#define LASER_PIN_2 A1 //orange
#define LASER_PIN_3 A2 //green
#define LASER_PIN_4 A3 //blue

Sardau, 2015-08-24:
noted thank you

Closed 2015-08-24.

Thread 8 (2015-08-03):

PS3 Eye Support

strawdog74, 2015-08-03:
Hi there,

I am using a PS3_Eye Webcam with the CL-Eye-Driver-5.3.0.0341 driver, which is supposed to support DirectShow however the camera is not being displayed in the drop-down list.

Do you know of anyone who has managed to get Sardauscan working with a PS3_Eye webcam?

Thanks // SD

Sardau, 2015-08-24:
I use the standart directshow routine to get the available camera (same as opencv). if you don't see it, it is probably not supported.

Closed 2016-03-10.

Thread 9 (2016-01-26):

Bad data due to stepper backlash

rockjim, 2016-01-26:
I find that because the stepper has some backlash in it, the first couple scan passes often have some bad data.  It seems like the easiest way to fix this would be to have the stepper take a few steps (or more) before the first scan to make sure to get even forward tension on the scanning bed.

Sardau, 2016-10-21:
noted

kariangel, 2017-02-05:
hello my friend i need to change  stepper (28BYJ-48) whith stepper 1.8 deg  200 steps
what i must change in firmware
thanks

Sardau, 2017-02-06:
Hello it depend of your stepper driver and your motor :

in the firmware,

configuration.h
#define HALFSTEP 8
#define REVOLUTION_STEP 4072
#define STEP_BY_MINMOVE 4

and in firmware.ino
AccelStepper stepper1(HALFSTEP, motorPin1, motorPin3, motorPin2, motorPin4);

for the specific values of the constructor of the accelstepper, see your wiring and the help of the accelstepper library.

kariangel, 2017-02-06:
Bonjour sardau et merci pour la réponse
J'ai le même type de driver que vous avez utilisé mais il peut aller
jusqu'à 2 A j'ai utilisé un moteur pas a pas de 1.5A\200pas  avec une
alimentation externe je voudrait modifié votre firmware pour avoir 200
pas/tour et non 2048 pas/tour
Merci mon amis

Le 6 févr. 2017 06:45, "Fabio Ferretti" <notifications@github.com> a écrit :

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

Sardau, 2017-02-06:
REVOLUTION_STEP est le nombre de step reel  (physique) pour faire un tour.

STEP_BY_MINMOVE est le rapport entre les step physique et logique.

le nombre de step logique  (ceux que le soft windows voit) => REVOLUTION_STEP/STEP_BY_MINMOVE;

Donc si par exemple tu as un moteur qui fait 200 pas par rotation, que ton stepper a 16 micosteps
=> REVOLUTION_STEP = 200*16
mais si tu veux que le soft n'en voit que 200 => tu fixe STEP_BY_MINMOVE  a 16 (car REVOLUTION_STEP /STEP_BY_MINMOVE  donne 200).

Cela dit, je ne vois pas pourquoi tu veux limiter le nombre de step pour un tour. garde le maximum pour ton hardware dans le firmware. et choisi plustot la "precision" dans la tache de scan (en gros cela change le Nbr de step entre 2 images)

kariangel, 2017-02-06:
Merci sardau
En faite je veut améliorer la qualité de scan et je veut utilisé un moteur
pas a pas plus stable pour avoir une rotation fluide
En tous cas bravo tu a fait du bon travail
Salut

Le 6 févr. 2017 10:50, "Fabio Ferretti" <notifications@github.com> a écrit :

REVOLUTION_STEP est le nombre de step reel (physique) pour faire un tour.

STEP_BY_MINMOVE est le rapport entre les step physique et logique.

le nombre de step logique (ceux que le soft windows voit) =>
REVOLUTION_STEP/STEP_BY_MINMOVE;

Donc si par exemple tu as un moteur qui fait 200 pas par rotation, que ton
stepper a 16 micosteps
=> REVOLUTION_STEP = 200*16
mais si tu veux que le soft n'en voit que 200 => tu fixe STEP_BY_MINMOVE a
16 (car REVOLUTION_STEP /STEP_BY_MINMOVE donne 200).

Cela dit, je ne vois pas pourquoi tu veux limiter le nombre de step pour un
tour. garde le maximum pour ton hardware dans le firmware. et choisi
plustot la "precision" dans la tache de scan (en gros cela change le Nbr de
step entre 2 images)

—
You are receiving this because you commented.
Reply to this email directly, view it on GitHub
<https://github.com/Sardau/Sardauscan/issues/9#issuecomment-277633469>, or mute
the thread
<https://github.com/notifications/unsubscribe-auth/AYY0x2CyjRJIU_5NZj7S0oa8YXzA5wVGks5rZuzOgaJpZM4HM-O8>
.

Sardau, 2017-02-06:
c'est le nombre de pas total qui est important pour la resolution 200 au lieu de 1000+(4072/4) => 5 fois moins de sample par tour.

kariangel, 2017-02-06:
Je vais utilisé le micro pas +réducteur
Es que l'arduino gère le micro pas?
Je vais utilisé le moteur 200 pas et je vais programmer l'arduino en micro
pas
Seulement j'ai un problèmes avec la compilation du firmware
Salut

Le 6 févr. 2017 11:34, "Fabio Ferretti" <notifications@github.com> a écrit :
>
> c'est le nombre de pas total qui est important pour la resolution 200 au
lieu de 1000+(4072/4) => 5 fois moins de sample par tour.
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

kariangel, 2017-02-13:
bonjour sardau
j'ai utilisé le scanner le résultat n'est pas vraiment fameux mais dans l'ensemble cava
je voulais juste savoir pour quoi tu a utiliser 4 lasers au lieu d'un?
j'ai constater que le soft fait un balayage de 10 degré et je voudrais augmenté la précision
c'est a dire faire un balayage de 1 ou 2 degré
comment je peut faire sa?
salut

Sardau, 2017-02-14:
4 laser = 4 vue differentes du meme profil ( mais le temps additionnel n'est pas fois 4 ;) )

Pour la presision du scan, il faut cliquer sur les petit engrenages a coté de la tache "scan".
 (chanque tache a ses propres options : dans la colone de gauche tu change le default, dans celle de droite uniquement pour le process couran)

il faut aussi allez dans "tune" et modifier le threshold pour avoir une ligne bien bien net. (tu peux aussi allez dans les config de la camera pour modifier l'exposition, cela aide pas mal)

un scan brut n'est pas top,

perso je fait un "scan"
puis un "laser" ou "angle", ( moyenne par angle ou sur les lasers "a la meme position")
puis un "build mesh"

kariangel, 2017-02-17:
bonsoir sardau
je n'arrive pas a enregistrer le scan je fait le save mais il ya rien le soft n'enregistre pas
merci

Sardau, 2017-02-18:
pour sauver le scan, il faut ajouter une tache de sauvegarde.

Si tu n'as pas de tache de "build mesh", tu ne peut sauver que dans des formats de "point cloud".

si tu as une tache qui reconstruit le modele (build mesh) tu peux sauvegarder dans un format d'objet mesh (stl et obj).

 perso je te conseil de faire un process scan + save .SAR
comme cela tu sauvegarde ton scan dans un format interne au soft.

ensuite tu peut faire un autre process ou tu load le sar puis tu ajoutes differentes taches pour toi essayer.

cela te permet de jouer avec les differentes taches sans devoir scanner a chaque fois.

c'est plus rapide quand tu tatonne dans les taches ;)

kariangel, 2017-02-18:
bonsoir  sardau
je voudrais savoir comment je peut augmenter la précision puisque tu la limité sur ton soft a 100
je voudrais l'augmenté a 300 ou 400
100 c'est peut l'angle est trop grand le scanner ne capte pas toutes les formes
merci

Sardau, 2017-02-19:
le 100 est un pourcentage : a 100 il turne par le nombre de step minimum que le firmware de l'arduino renseigne.

kariangel, 2017-02-21:
Bonjour sardau
J'ai vue sur youtube un type a utiliser hardware sardauscan et software
horis scan c'est possible
Merci

Le 19 févr. 2017 09:10, "Fabio Ferretti" <notifications@github.com> a
écrit :

le 100 est un pourcentage : a 100 il turne par le nombre de step minimum
que le firmware de l'arduino renseigne.

—
You are receiving this because you commented.
Reply to this email directly, view it on GitHub
<https://github.com/Sardau/Sardauscan/issues/9#issuecomment-280903418>, or mute
the thread
<https://github.com/notifications/unsubscribe-auth/AYY0x5NtfH-T7dpLEl_9S4QIKN1cqhbsks5rd_j_gaJpZM4HM-O8>
.

Sardau, 2017-02-21:
je sais qu'une personne a modifier le firmware du horus pour le faire fonctionner avec le hardware du sardauscan.

ps: je lui ai demander sur instructable de partager ses modifications, mais je n'ai pas eut de réponse.
Si tu as des liens vers ce firmware, cela m’intéresse d'essayé ;)

kariangel, 2017-02-21:
Pour quoi ne pas modifier le soft sardauscan pour faire un balayage en
continue c'est a dire le moteur tourne en continue et en petite vitesse et
le laser allumer en continue et le soft enregistre le résultat comme sa on
aura un résultat meilleur. Le même système que David scan
Merci

Le 21 févr. 2017 09:40, "Fabio Ferretti" <notifications@github.com> a
écrit :

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

Sardau, 2017-02-21:
Si le moteur tourne on ne peut pas prendre 5 images a la même position. (une de référence et 1 par lazer. voir "How does it work?" dans http://www.instructables.com/id/Build-a-30-laser/ )

la détection des lasers en plein jour est déjà difficile a "tuner" pour beaucoup de personnes, mais si en plus on a pas d'image de référence, ce serait encore plus compliqué..

Cela dit, si tu connais une autre technique, libre a toi de faire ta propre tache de scan via un plugin.

Closed 2019-02-28.

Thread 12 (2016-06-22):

Does it work with two lasers?

bond4u, 2016-06-22:
I have two lasers.
Calibrate > Quick scan
Shows fours shapes:
1. Laser0 - red
2. Laser1 - green
3. light blue
4. purple

bond4u, 2016-06-22:
https://goo.gl/photos/a8QyXE4NxfLhCrwK8

Sardau, 2016-10-21:
hello,

your camera is not perfectly vertical.
your "tune" of the laser doesn't seems ok ( too many error)
i think you must redone your calivration : 1mm is a HUGE error in physical calibration and in build dimention.

Closed 2019-02-28.

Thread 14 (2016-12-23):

Nothing moves, Sardauscan command doesn't return Yes

Crazydoub, 2016-12-23:
Hi dear friend and thanks for your work

I've got a problem with firmware
I've uploaded program to arduino,
When i got to serial monitor, it shows
`Sardauscan V0.1a`
When i try to type 'Sardauscan' it returns nothing.
I try to connect to arduino with Sardauscan scanning software, it connects well and laser control works.
I tried to use accel-stepper exemples, motor controller works and motor too!
Seems there's a problem but i really can't find where!

Closed 2016-12-23.

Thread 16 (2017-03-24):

value for x dimension

scvette, 2017-03-24:

scvette, 2017-03-24:
I have been using my scanner for a long while and cannot find how to measure the X axis value for the lasers. Y and Z values are well documented, What is the dimension of the X value? Is it from the tip of the camera to the tip of the laser? Is it automatically determined when an accurate angle value input? Please add x info to the nice new docs.
Thanks for a great scanner!

Sardau, 2019-02-28:
All the measurment from the center of rotation of the table.

if you place yourself at the "camera" place, you are at X=0 .  X>0 is on your right.

BTW : I've introduce a angle that is editable in the config bacause it is easier to print a "protractor". place it on the center of rotation and read the angle.

Closed 2019-02-28.

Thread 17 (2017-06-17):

Error with Sardauscan Software

GuyzmoHobbit, 2017-06-17:
Hello,

i have the following error with GUI application, when i want to configure laser, plate, or camera :

Error ---
Impossible de charger un ou plusieurs des types requis. Extrayez la propriété LoaderExceptions pour plus d'informations.

HelpLink ---

Source ---
mscorlib
StackTrace ---
   à System.Reflection.RuntimeModule.GetTypes(RuntimeModule module)

   à System.Reflection.Assembly.GetTypes()

   à Sardauscan.Core.Reflector.<get_AllTypes>b__0(Assembly assembly)

   à System.Linq.Enumerable.<SelectManyIterator>d__14`2.MoveNext()

   à System.Collections.Generic.List`1..ctor(IEnumerable`1 collection)

   à System.Linq.Enumerable.ToList[TSource](IEnumerable`1 source)

   à Sardauscan.Core.Reflector.get_AllTypes()

   à Sardauscan.Core.Reflector.GetProviders(Type baseType)

   à Sardauscan.Gui.Controls.HardwareStatusControl.Button_Click(Object sender, EventArgs e)

   à System.Windows.Forms.Control.WmMouseUp(Message& m, MouseButtons button, Int32 clicks)

   à System.Windows.Forms.Control.WndProc(Message& m)

   à System.Windows.Forms.NativeWindow.Callback(IntPtr hWnd, Int32 msg, IntPtr wparam, IntPtr lparam)
TargetSite ---
System.Type[] GetTypes(System.Reflection.RuntimeModule)

I dont' see any plugins in the interface...

Can you help (Windows 7)

Sardau, 2019-02-28:
sorry but i need more informations.

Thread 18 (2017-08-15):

Accuracy

percramer, 2017-08-15:
Hi,

Just found your project. I was wondering how accurate it is? We own a David3d scanner (hp now), so i could do Some compare. But maybe there already is Some info on this?

podarok, 2018-01-10:
@percramer it depends from the camera resolution you'll be using for scan
I'm not sure if the software support other cameras atm, but I belive it is not that hard to make it working for High-Resolution cameras

Sardau, 2019-02-28:
it depend on your camera, your build size and the quality of your calibration.

Closed 2019-02-28.

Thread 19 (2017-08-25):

programmazione arduino per Sarduscan

StefanoDMR75, 2017-08-25:
Buongiorno a tutti, sono nuovo in questo tipo di cose, non riesco a mettere il frimware e tutto il resto su arduino nano, qualsiasi file scaricato mi da codici di errori. Qualcuno potrebbe postare una procedura passo passo per programmare la arduino per questo progetto di Sarduscan? Grazie

Sardau, 2019-02-28:
Sotty i don't speak italian... i know my name... but i'm not italian :)

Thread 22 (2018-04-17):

jagged 3d model

supermariobis, 2018-04-17:
Hi! Thanks 4 the project, I made the scanner but I have a problem: the model that create the software is confused, I try to scan a cube but in "quick scan" I see strange lines ( not a square).
Who can help me?

P.s. sorry for my english

Sardau, 2019-02-28:
Hello i only can  refer you to the Documentation on how to calibrate: be aware that 1mm off result in huge computation errors.

Closed 2019-02-28.

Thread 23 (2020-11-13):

error upon opening sardauscan

jmartens2, 2020-11-13:
everytime it tries to open sardauscan.exe windows says the program has stopped working and checks for a solution. im running win 7 32 bit os.

jmartens2, 2020-11-19:
wow. you can hear a pin drop. hi, anybody able to help a friend????

nipfuh, 2021-01-10:
v0.0.0.3 (https://github.com/Sardau/Sardauscan/releases/tag/0.0.0.3) at least opens for me, I haven't gotten around to actually test the scanning but maybe you can give it a shot

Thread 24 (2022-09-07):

Configuring "Turn table" and "Laser(s)" in Sardauscan software

stefanpns, 2022-09-07:
My issue:
when i try to configure the "Turn table" and "Laser(s)" in the new window after selecting in the field
the "USB Serial Device (COM3)" i got nothing. It is like in the tutorial document on the page 4. where is picture and sentence: "If nothing is detected, do not hesitate to unplug / reconnect the Arduino card".

I have tried following:

1. First when i tried just the arduino hardware (commands like "l 0 1"...) i have to change the term from "\r" to "\n" in order to process commands. So i thought maybe the term making the problem for detecting nothing. I have tried both terms but no success.
2. I have tried to unplug/reconnect the Arduino card but no success.
3. I have tried to plug in every USB port my Arduino but no success.
Can you tell me if You know if anyone had the same issue?

stefanpns, 2022-09-08:
I have solved this by commenting the lines:
```
//#define SERIALCOMMANDDEBUG 1
//#undef SERIALCOMMANDDEBUG
```
in file _SerialCommand.h_

Closed 2022-09-08.

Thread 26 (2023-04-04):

Sardauscan for Mac

YarelisAcevedo, 2023-04-04:
This is not an issue per se with the software, but I'm currently building your 3D scanner. My only issue is that I have a Mac, and I would love to be able to run it here. Is there any possibility to write it for Mac?? (if not probably in the future I would love to translate this to Mac, but I don't have much time).

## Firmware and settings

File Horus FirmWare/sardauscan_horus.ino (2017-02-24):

/*
 * Modified Firmware from Sardauscan (https://github.com/Sardau/Sardauscan) 
 * to make the Hardware compatible with Horus 3d Scan software from BQ (https://github.com/bqlabs/horus)
 * 
 * The firmware understands just the basic G-Codes for turning the tables and enabling or disabling the lasers 
 * (setting the speed does not work) but that's enough for scanning.
 * Feel free to modify or extend the code
 * 
 * You need the AccelStepper library from https://github.com/adafruit/AccelStepper
 *  
 *  Andi M.
 */

#include <AccelStepper.h>
#include "configuration.h"

char SerialBuffer[255];
unsigned char Serialpos=0;

AccelStepper stepper1(HALFSTEP, motorPin1, motorPin3, motorPin2, motorPin4);

int RotationToSteps(int rotation)
{
  return rotation*STEP_BY_MINMOVE;
}

void HandleSerial(void)
{
  SerialBuffer[Serialpos]=Serial.read();
  if(SerialBuffer[Serialpos]==0x18)
  {
      Serial.print("\r\nHorus 0.2 ['$' for help]\r\n");
      Serialpos=0;
  }
  else if(SerialBuffer[Serialpos]=='\r' || SerialBuffer[Serialpos]=='\n')
  {
    SerialBuffer[Serialpos+1]='\0';
    if(!strcmp(SerialBuffer,"$\r") || !strcmp(SerialBuffer,"$\n") || !strcmp(SerialBuffer,"$\r\n")) //answer to "$", not needed
    {
      Serial.println("$$ (view settings)");
      Serial.println("$# (view # parameters)");
      Serial.println("$G (view parser state)");
      Serial.println("$I (view build info)");
      Serial.println("$N (view startup blocks)");
      Serial.println("$x=value (save setting)");
      Serial.println("$Nx=line (save startup block)");
      Serial.println("$C (check gcode mode)");
      Serial.println("$X (kill alarm lock)");
      Serial.println("~ (cycle start)");
      Serial.println("! (feed hold)");
      Serial.println("? (current status)");
      Serial.println("ctrl-x (reset)");
      Serial.println("ok");
    }
    else if(!strncmp(SerialBuffer,"G50",3))     //Zero all
    {
      stepper1.setCurrentPosition(0);
      Serial.println("ok");
    }
    else if(!strncmp(SerialBuffer,"M0",2))     //Pause
    {
      Serial.println("ok");
    }
    else if(!strncmp(SerialBuffer,"M2",2))     //Reset
    {
      Serial.println("ok");
    }
    else if(!strncmp(SerialBuffer,"M17",3))     //Enable Steppers
    {
      stepper1.enableOutputs();
      Serial.println("ok");
    }
    else if(!strncmp(SerialBuffer,"M18",3))     //Disable Steppers
    {
      stepper1.disableOutputs();
      Serial.println("ok");
    }
    else if(!strncmp(SerialBuffer,"M50",3))     //Read LDR
    {
      Serial.println("ok");
    }
    else if(!strncmp(SerialBuffer,"M70T",4))     //Laser off
    {
      if(SerialBuffer[4]=='1')
        digitalWrite( LASER_PIN_1, 0);
      if(SerialBuffer[4]=='2')
        digitalWrite( LASER_PIN_4, 0);
      Serial.println("ok");
    }
    else if(!strncmp(SerialBuffer,"M71T",4))     //Laser on
    {
      if(SerialBuffer[4]=='1')
        digitalWrite( LASER_PIN_1, 1);
      if(SerialBuffer[4]=='2')
        digitalWrite( LASER_PIN_4, 1);
      Serial.println("ok");
    }
    else if(!strncmp(SerialBuffer,"G1",2))     //movement
    {
      if(SerialBuffer[2]=='F')              //speed (not working)
      {
        char arg2[10];
        for(int i=4;i<strlen(SerialBuffer);i++)
        {
          arg2[i-4]=SerialBuffer[i];
        }
        long rotspeed=atoi(arg2);
//        stepper1.setMaxSpeed(rotspeed);
      }
      if(SerialBuffer[2]=='X')              // move to degree
      {
        char arg2[10];
        for(int i=3;i<strlen(SerialBuffer);i++)
        {
          arg2[i-3]=SerialBuffer[i];
        }
        long pos=(atoi(arg2));
        pos=(pos*512)/360;
        stepper1.moveTo(RotationToSteps(pos));
        stepper1.runToPosition();
      }
      Serial.println("ok");
    }
    else if(!strncmp(SerialBuffer,"$1",2))     //
    {
      Serial.println("ok");
    }
    Serialpos=0;
  }
  else
    Serialpos++;
}

void setup() {
  stepper1.setMaxSpeed(500.0);
  stepper1.setAcceleration(200.0);
  stepper1.setSpeed(400);
  stepper1.moveTo(0);
  stepper1.runToPosition();
  Serial.begin(SERIAL_BAUD);
 
  pinMode(LASER_PIN_1, OUTPUT);
  pinMode(LASER_PIN_2, OUTPUT);
  pinMode(LASER_PIN_3, OUTPUT);
  pinMode(LASER_PIN_4, OUTPUT);
  digitalWrite(LASER_PIN_1, LOW);
  digitalWrite(LASER_PIN_2, LOW);
  digitalWrite(LASER_PIN_3, LOW);
  digitalWrite(LASER_PIN_4, LOW);

  Serial.print("\r\nHorus 0.2 ['$' for help]\r\n"); //send identification string at startup to make Horus recognise the board

  Serial.flush();
}


void loop() {
  if(Serial.available())
    HandleSerial();
  Serial.flush();
}

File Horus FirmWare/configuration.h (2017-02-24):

#ifndef CONFIGURATION_h
#define CONFIGURATION_h

#define FIRMWARE_VERSION "Sardauscan V0.1a"

#define SERIAL_BAUD 115200
//57600

// Motor definitions
#define motorPin1  2     // IN1 on the ULN2003 driver 1
#define motorPin2  3     // IN2 on the ULN2003 driver 1
#define motorPin3  4     // IN3 on the ULN2003 driver 1
#define motorPin4  5     // IN4 on the ULN2003 driver 1

//tips (from Mark Benson)
//If anyone else is having problems with a BYJ48 stepper not doing anything, 
//change the HALFSTEP value to 4 & REVOLUTION_STEP to 2048
#define HALFSTEP 4
#define REVOLUTION_STEP 4096
#define STEP_BY_MINMOVE 4  // move by STEP_BY_MINMOVE (to avoid power loss when position is between step) 

#define LASER_COUNT 4
#define LASER_PIN_1 A1 //yellow
#define LASER_PIN_2 A2 //orange
#define LASER_PIN_3 A3 //green
#define LASER_PIN_4 13 //blue

#endif

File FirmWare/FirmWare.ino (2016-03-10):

#include "SerialCommand.h"
#include <AccelStepper.h>
#include "configuration.h"
/*
Commands :
identity

sardauscan =>ask if this is a sardaucan => response "yes" //

laser :
L => ask laser configuration => response number of lasers
L x => ask status of laser index X
      => 'x' laser number
L x y  => turn laser on or off 
    'x' laser number
    'y' state: 0=off 1=on

Table :
T => table position
T S => return the number of steps for a revolution 
T C => Set Current position as 0 (for absolute positionning
T R xxx => rotate relatively xxx steps 
T A xxx => turn position absolute xxx steps 

unknow command 
=> response "Hun?"

*/

AccelStepper stepper1(HALFSTEP, motorPin1, motorPin3, motorPin2, motorPin4);


SerialCommand SCmd;

int RotationToSteps(int rotation)
{
  return rotation*STEP_BY_MINMOVE;
}
int StepsToRotation(int rot)
{
  return rot/STEP_BY_MINMOVE;
}
void Identification()
{
	Serial.println("yes");
}
void Hun()
{
	Serial.println("Hun?");
}
void TableCommand()
{
	 char *arg; 
	 arg = SCmd.next(); 
	 if (arg != NULL) 
	 {
		 if(arg[0]=='R'||arg[0]=='r') // T R
		 {
                    char *arg2 = SCmd.next(); 
                    int pos=atoi(arg2);
                    stepper1.move(RotationToSteps(pos));
                    stepper1.runToPosition();
		    Serial.print("RELATIVE ROTATION :"); 
		    Serial.print(pos); 
		    Serial.print(" => "); 
		    Serial.println(StepsToRotation(stepper1.currentPosition())); 
		 }
		 else if(arg[0]=='A'||arg[0]=='a') // T A
		 {
                    char *arg2 = SCmd.next(); 
                    int pos=atoi(arg2);
                    stepper1.moveTo(RotationToSteps(pos));
                    stepper1.runToPosition();
		    Serial.print("ABSOLUTE ROTATION "); 
		    Serial.print(pos); 
		    Serial.print(" => "); 
		    Serial.println(StepsToRotation(stepper1.currentPosition())); 
		 }
		 else if(arg[0]=='S'||arg[0]=='s') //T S
                  {
		    Serial.print("REVOLUTION STEPS "); 
		    Serial.print(" => "); 
		    Serial.println(StepsToRotation(REVOLUTION_STEP)); 
                  }
		 else if(arg[0]=='C' ||arg[0]=='c') //T C
                  {
                    stepper1.setCurrentPosition(0);
		    Serial.print("RESET CUTTENT POSITION "); 
		    Serial.print(" => "); 
		    Serial.println(StepsToRotation(stepper1.currentPosition())); 
                  }
                 else
                 {
		    Serial.print("Unknown Table command :"); 
		    Serial.println(arg); 
                 }
	 } 
  else {
     Serial.print("Position "); 
    Serial.println(StepsToRotation(stepper1.currentPosition())); 
  }
}
int getLaserPin(int laserIndex)
{
       if(laserIndex==0)
         return LASER_PIN_1; 
       else if(laserIndex==1)
         return LASER_PIN_2; 
       else if(laserIndex==2)
         return LASER_PIN_3; 
       else if(laserIndex==3)
         return LASER_PIN_4; 
       else
         return (-1); 
}

void LaserCommand()
{
  char *arg; 
  arg = SCmd.next(); 
  if (arg != NULL) 
  {
    int laserIndex=atoi(arg);
    char *arg2 = SCmd.next(); 
    if (arg2 == NULL) 
    {
       Serial.print("LASER_STATE: "); 
       Serial.print(laserIndex); 
       int pin =getLaserPin(laserIndex);
       Serial.print("("); 
       Serial.print(pin); 
       Serial.print(") = "); 
       if(pin>=0)
         Serial.println(digitalRead(pin)); 
       else
         Serial.println(-1); 
    }
    else 
    {
       int laserState = atoi(arg2);
       int pin =getLaserPin(laserIndex);
       if(pin>=0)
        digitalWrite( pin, laserState==1?HIGH:LOW);
       Serial.print("SET_LASER: "); 
       Serial.print(laserIndex); 
       Serial.print("("); 
       Serial.print(pin); 
       Serial.print(") = "); 
      Serial.println(digitalRead(pin)); 
     }
   }
   else 
   {
    Serial.print("LASER_COUNT: "); 
    Serial.println(LASER_COUNT); 
   }
}



void setup() {
  stepper1.setMaxSpeed(500.0);
  stepper1.setAcceleration(200.0);
  stepper1.setSpeed(400);
  stepper1.moveTo(0);
  stepper1.runToPosition();
  Serial.begin(SERIAL_BAUD);
 
  pinMode(LASER_PIN_1, OUTPUT);
  pinMode(LASER_PIN_2, OUTPUT);
  pinMode(LASER_PIN_3, OUTPUT);
  pinMode(LASER_PIN_4, OUTPUT);
  digitalWrite(LASER_PIN_1, LOW);
  digitalWrite(LASER_PIN_2, LOW);
  digitalWrite(LASER_PIN_3, LOW);
  digitalWrite(LASER_PIN_4, LOW);
  SCmd.addCommand("sardauscan",Identification);
  SCmd.addCommand("T",TableCommand);
  SCmd.addCommand("t",TableCommand);
  SCmd.addCommand("L",LaserCommand);
  SCmd.addCommand("l",LaserCommand);
  SCmd.addDefaultHandler(Hun);
  Serial.println(FIRMWARE_VERSION);
  Serial.flush();
}


void loop() {
	SCmd.readSerial();     // We don't do much, just process serial commands
        Serial.flush();
}

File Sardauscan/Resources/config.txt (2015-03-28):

<xml>
  <LASER>
    <MAGNITUDE_THRESHOLD value="30" type="System.Int32" />
    <MIN_WIDTH value="1" type="System.Int32" />
    <MAX_WIDTH value="60" type="System.Int32" />
    <FADE_DELAY value="100" type="System.Int32" />
  </LASER>
  <LASER_0>
    <X value="120" type="System.Double" />
    <Y value="75" type="System.Double" />
    <Z value="207,846096908265" type="System.Double" />
    <DEFAULTCOLOR value="Red" type="System.Drawing.Color" />
  </LASER_0>
  <LASER_1>
    <X value="56,94019" type="System.Single" />
    <Y value="75" type="System.Double" />
    <Z value="212,5037" type="System.Single" />
    <DEFAULTCOLOR value="Green" type="System.Drawing.Color" />
  </LASER_1>
  <LASER_2>
    <X value="-56,94019" type="System.Single" />
    <Y value="75" type="System.Double" />
    <Z value="212,5037" type="System.Single" />
    <DEFAULTCOLOR value="Blue" type="System.Drawing.Color" />
  </LASER_2>
  <LASER_3>
    <X value="-118,0951" type="System.Single" />
    <Y value="75" type="System.Double" />
    <Z value="208,9343" type="System.Single" />
    <DEFAULTCOLOR value="Cyan" type="System.Drawing.Color" />
  </LASER_3>
  <CAMERA>
    <X value="0" type="System.Single" />
    <Y value="75" type="System.Double" />
    <Z value="240" type="System.Double" />
  </CAMERA>
  <COM>
    <LASER_TIMEOUT value="10" type="System.Int32" />
    <TABLE_TIMEOUT value="500" type="System.Int32" />
    <CONNECTION_TIMEOUT value="5000" type="System.Int32" />
    <INFO_TIMEOUT value="1000" type="System.Int32" />
  </COM>
  <SCANNER>
    <PRECISION value="75" type="System.Int32" />
    <DEFAULTCOLOR value="LightGrey" type="System.Drawing.Color" />
    <USEBITMAP value="False" type="System.Boolean" />
    <MESHBUILD value="True" type="System.Boolean" />
    <CENTERDETECTIONMODE value="MassHarmonicCenter" type="Sardauscan.Core.ImageProcessor+eLaserDetectionMode" />
    <CALIBRATIONPRECISION value="50" type="System.Int32" />
  </SCANNER>
  <TABLE>
    <HEIGHT value="150" type="System.Single" />
    <DIAMETER value="200" type="System.Single" />
  </TABLE>
  <OPENGL>
    <SHOWSCENECOLOR value="True" type="System.Boolean" />
    <SHOWBOUNDINGBOX value="True" type="System.Boolean" />
    <DEFAULTMATERIAL value="White rubber" type="System.String" />
    <LIGHTNING value="True" type="System.Boolean" />
    <SMOOTH value="True" type="System.Boolean" />
    <PROJECTION value="False" type="System.Boolean" />
    <WIREFRAME value="False" type="System.Boolean" />
  </OPENGL>
  <SYSTEM>
    <MAXTHREADS value="8" type="System.Int32" />
  </SYSTEM>
</xml>

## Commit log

2015-03-02 Sardauscan
    under 30$ open source 3d laser scanner
2015-03-02 adding STL
    [CORNER.stl, Camera_HOLDER_LOWER_PART.stl, arm_left.stl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]
2015-03-02 adding firmware
    [configuration.h]
2015-03-02 filling bom
2015-03-04 Adding plugin sample
2015-03-04 Adding License and some comment to the Plugin sample
2015-03-05 ressource / license and sample plugin comment
2015-03-08 last ressources
    [calibration.stl, config.txt]
2015-03-08 T-slot for M4
    [M4_tslot_nut.stl]
2015-03-08 first release
    [3d Scan.sdf]
2015-03-09 Dimention corrections and stl orientation
    Link laser Y to Camera Y
    Correction of sensor height/width and focal length to match the hercume
    hd twist.
    rotate the point coordine when saving stl
2015-03-09 camera sensor size tweak
2015-03-12 some minor crash when no laser selected + v2
2015-03-14 switching to visual 2013, switching from float to double, ICP try, add Merge by angle
2015-03-16 adding wiring info + some change to angle marge
2015-03-16 changing zomm in calibration & add a top view button in 3d control
2015-03-17 changing 3d navigation && make calibration room for other interfaces
2015-03-18 Correction of dimention crash when aberant values, and default config update
    [config.txt]
2015-03-23 Adding Matk Benson tips
    [configuration.h]
2015-03-28 V4 : faster, better cam support , correction internationla .sar reaading, grab pictures task, many more
    [config.txt]
2015-04-04 model update
    [box_door.stl]
2015-05-29 adding genius holder
    [Camera_HOLDER_Lower_genius_PART.stl, Camera_HOLDER_Upper_genius_PART.stl]
2015-06-02 match the schema
    [configuration.h]
2016-03-10 coloring laser everywhere
    [calibrationV2.stl]
2017-02-24 Adding Horus Firmware
    This Firmware is designed to use the Sardauscan Hardware with the BQ
    Horus software. ( https://github.com/bqlabs/horus )
    It was developped by Andi Moesenlechner.
    Big thanks to him
    [configuration.h]
